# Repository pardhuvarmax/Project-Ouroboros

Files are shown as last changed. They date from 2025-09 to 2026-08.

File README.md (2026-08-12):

# Project Ouroboros – Unified Wireless Security Research
> ⚠️ **Disclaimer:** This project is for **educational, research, and ethical security purposes only**. Misuse of hardware or software is strictly the responsibility of the user.

---

## 🌐 Overview

**Project Ouroboros** is a **modular, dual-use cybersecurity platform** encompassing multiple ESP32-based hardware and firmware modules for **wireless defense, monitoring, and controlled research/offense experiments**.

It is structured as a parent ecosystem:

* **Blue Pill (Passive Development) :** Consumer-friendly, multi-layer defense shield (Wi-Fi, BLE, Sub-GHz) with anomaly detection and automated mitigation.
* **OuroMini:** Rapid-prototype dual-use demo board (15-day expo build) showcasing real-time wireless telemetry, visualization, and ghost traces.

The Ouroboros philosophy: **eternal cycle of attack & defense** — integrating visualization, telemetry, and interactive demos in a single hardware/firmware ecosystem.

---

## 🔹 Core Objectives

* **Defense:** Protect home, personal, and IoT networks from Wi-Fi, BLE, Sub-GHz attacks.
* **Research:** Safe experimentation of offensive tools for learning and controlled testing.
* **Visualization:** Real-time telemetry, ghost traces, waterfall spectrums, and dashboards for expos or lab demos.
* **Rapid Deployment:** Prebuilt `.bin` firmware, modular hardware, and standardized flashing for fast prototyping.
* **Extensibility:** Supports TinyML, AI-assisted anomaly detection, and additional RF front-ends.

---

## 🏗️ Sub-Projects & Modules

### Blue Pill – Defensive Shield

**Purpose:** Consumer-ready Wi-Fi/BLE/Sub-GHz network protection.

**Features:**

* Real-time intrusion detection (deauth, rogue AP, spoofing).
* TinyML anomaly detection for smarter threat recognition.
* Active countermeasures: automated mitigation, reconnection, and hardened configs.
* Spectrum visualization: waterfall graphs on OLED/TFT.
* Logging & optional dashboard telemetry.

**Hardware & Firmware:**

* ESP32-U/WROOM-32E, OLED/TFT, optional Sub-GHz & BLE modules.
* Firmware modularity allows independent updates for each protocol.

**Resources:**

* [Blue Pill Docs](./BluePill/Documentations)

---

### OuroMini – 15-Day Expo Prototype

**Purpose:** Rapid 15-day dual-use prototype for expos & demos.

**Highlights:**

* Real-time scanning: Wi-Fi, BLE, Sub-GHz.
* OLED visualization: RSSI bars, waterfall graphs, ghost-traces.
* Dual-mode toggle: Defensive vs. Research.
* SD card logging and optional dashboard telemetry.

**Hardware:** ESP32 MCU, OLED, minimal peripherals, external antennas.

**Firmware:** Modular scanning, menu-driven UI, safe demo constraints.

**Docs:** 
- [Ouromini Abstract](OuroMini/docs/ABSTRACT.md)
- [OuroMini Expo Documentation](./OuroMini/docs/EXPO.md)  
- [Architecture & Firmware Details](./OuroMini/docs/ARCHITECTURE.md)

---

### Modules

| Module | Purpose | Notes |
| --- | --- | --- |
| CC1101 / Sub-GHz | RF monitoring & replay | 315/433/868/915 MHz bands |
| NRF24L01 | Mesh/network testing | 2.4 GHz experimentation |
| PN532 / RFID-NFC | Tag scanning & emulation | Access control research |
| IR Transceiver | Consumer device capture/replay | NEC, RC5, Samsung, etc. |
| FM / Audio | Frequency scanning & demo | Visualization only |

---

## 🛠️ Hardware Requirements

**Core MCU:**

* ESP32-U / S3 for more RAM and peripherals.

**Optional:**

* OLED / TFT display (visualization & menus)
* External antennas for Wi-Fi/BLE/Sub-GHz
* Shields/modules for advanced research

---

## 💻 Software Stack

**Firmware Base:**

* [ESP-IDF](https://github.com/espressif/esp-idf)
* [Arduino-ESP32](https://github.com/espressif/arduino-esp32)

**Key Libraries:**

* WiFi, BLE, RadioLib (Sub-GHz)
* TensorFlow Lite Micro (TinyML)
* ArduinoJson, LittleFS, ESPAsyncWebServer
* U8g2, TFT_eSPI, LVGL for visualization

**Optional Tools:**

* HackRF / RTL-SDR for advanced RF
* Edge Impulse / TinyML SDKs

---

## 📂 Directory Structure

```
├───.github
├───BluePill
├───RedPill
├───OuroMini
│   ├───dashboard
│   ├───docs
│   ├───firmware
│   ├───graphics
│   ├───hardware
│   ├───media
│   └───tools
└───Docs
```

---

## 📚 Learning & Contribution Roadmap

1. Learn **ESP32 basics** → Wi-Fi, BLE, FreeRTOS.
2. Implement **Wi-Fi monitoring & defense** → deauth, rogue AP detection.
3. Explore **BLE & Sub-GHz experimentation** → spoofing, jamming, replay attacks.
4. Add **visualization & dashboards** → OLED/TFT/ESPAsyncWebServer.
5. Integrate **TinyML / AI models** → anomaly detection for defense.
6. Combine **offensive & defensive modules** → multitasking with FreeRTOS.
7. Extend **Shields & peripherals** → advanced RF and sensor experiments.

---

## 🔗 References

* [Espressif ESP32 Documentation](https://docs.espressif.com)
* [OWASP Wi-Fi Security Guide](https://owasp.org/www-project-wi-fi-security-testing-guide/)
* [NIST Wi-Fi Security Guidelines (SP 800-153)](https://csrc.nist.gov/publications/detail/sp/800-153/final)
* [HackRF Spectrum Analyzer](https://github.com/pavsa/hackrf-spectrum-analyzer)
* [TensorFlow Lite Micro](https://www.tensorflow.org/lite/microcontrollers)
* [Edge Impulse](https://edgeimpulse.com)

---

## 📜 License

**Project Ouroboros** © 2025 
Licensed under **GNU GPL-3.0** – use, modify, and redistribute under GPL terms. See [LICENSE](LICENSE).

## Credits & Attribution

- OuroMini's firmware is derived from ESP32 Marauder by Just Call Me Koko, originally released under the MIT License (Copyright © 2020 Just Call Me Koko). Marauder was itself inspired by Spacehuhn's esp8266_deauther.
What OuroMini changes: ported to ESP32-WROOM-32 as a headless target, removed the display, touch and on-device menu subsystems, and rebuilt the interaction layer around a web dashboard and serial/UART interface. See docs/ARCHITECTURE.md for the full breakdown.

- OuroMini as a whole is licensed under GNU GPL-3.0. The original MIT-licensed Marauder components remain under their original terms, and the upstream notice is retained in LICENSE-MIT.

---

✅ **This README serves as the central hub** for the entire Ouroboros ecosystem: **Blue Pill, Red Pill, OuroMini, Shields, and optional modules**, providing newcomers and contributors with the **complete project overview, architecture, and references**.

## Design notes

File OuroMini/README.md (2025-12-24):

# OuroMini Logo

**Ouroboros Mini (OuroMini)** — *ESP32-based experimental wireless monitoring & security testing platform (headless variant)*
Engineered as a **15-day rapid prototype**, OuroMini focuses on **dual-use** capabilities (defensive monitoring + controlled offensive research) for educational, research and expo demonstrations.
This document is the **headless / ESP32-WROOM-32 only** edition — all features and notes reflect that hardware constraint.

---

## 🔬 Project Objective

1. Deliver a **compact, cross-protocol wireless research platform** focused on capabilities realistically supported by the ESP32-WROOM32: **Wi-Fi (2.4 GHz)** and **Bluetooth Low Energy (BLE)**, plus IR and simple GPIO peripherals where hardware is present.
2. Provide **real-time telemetry & visualization** via a web dashboard and serial/UART (headless device → browser/dashboard on host).
3. Enable **signal capture and export** for offline analysis and demonstration (handshake export, packet logs).
4. Demonstrate **wireless anomaly detection, telemetry visualization, and repeatable expo demo sequences**.
5. Act as a **modular research artifact** (firmware + logging + demo scripts) for teaching and conferences.

---

## ⚠️ Dual-Use & Legal Considerations

Warning

> **Warning:** OuroMini is intended solely for ethical research, education and authorized security testing. Unauthorized use on networks/devices you do not own or have explicit permission to test is illegal. Comply with local wireless regulations (FCC/CE/others). Operators are responsible for lawful use. The project authors disclaim liability for misuse.

---

## ⚙️ Full Feature Set

| Protocol Layer | Features | Notes |
| --- | --- | --- |
| **Wi-Fi (2.4 GHz)** | - Network scanning (active + passive), AP/client enumeration, RSSI mapping<br>- Promiscuous-mode packet capture (2.4 GHz frames) & basic frame logging<br>- WPA handshake capture (exportable for offline cracking workflows)<br>- Targeted 2.4 GHz deauthentication (single & multi-target)<br>- Beacon creation / fake AP (SSID advertise / SSID flood)<br>- Evil Portal (captive-AP + hosted captive web page for demo/credential capture)<br>- Wardriving (scan + time-stamped LittleFS/SD logging) | **Headless ESP32-WROOM32 only — NO 5 GHz.** DPI beyond basic frame capture is limited by MCU resources. Use offensive actions only in authorized demos. |
| **Bluetooth (BLE)** | - BLE scanning (advertisements, RSSI logging) and presence tracking<br>- BLE advertising (beacon / peripheral emulation)<br>- Basic GATT server (simple characteristic read/write demos) | BLE features use the ESP32 BLE stack. Complex OS-level HID injection or advanced MITM is unreliable and platform-dependent. |
| **IR / GPIO (optional)** | - IR capture & replay sequences (if IR TX/RX hardware present)<br>- GPIO inputs (kill-switch) and outputs for LED indicators / external triggers | Optional per-device hardware. IR active features require an IR transmitter module fitted to the board. |
| **System / UX / Ops** | - LittleFS / SD capture logging (timestamped files)<br>- Web dashboard & WebSocket telemetry (hosted on AP/STA by the ESP)<br>- HTTP API / Web CLI endpoints for remote control (headless UI)<br>- OTA firmware update support (HTTP / PlatformIO compatible)<br>- UART / Serial CLI (local console) for interactive use<br>- Thermal sensor readout (internal temp) & runtime reporting<br>- Kill-switch GPIO input (hardware emergency disable handler)<br>- Rate-limiting controls for floods (configurable values)<br>- Timestamped operator/action logging to LittleFS | Headless operation — UI exposed via web dashboard or serial. All features above are implementable on stock WROOM32. |

---

## OuroMini Feature Classification: Defensive, Dual-Use, and Offensive Capabilities

| Category | Count | Example Features / Notes |
| ---: | ----: | --- |
| **Defensive** | 12 | Passive monitoring and analysis: <br>- Wi-Fi scanning (passive/active), AP/client enumeration, RSSI mapping<br>- BLE scanning & beacon tracking<br>- Promiscuous frame capture (2.4 GHz) & WPA handshake capture (for offline analysis)<br>- Wardriving + timestamped LittleFS/SD logging<br>- LittleFS/SD logging & operator/action audit trail<br>- Web dashboard & WebSocket telemetry (read/visualize)<br>- Thermal sensor reporting & UART CLI. |
| **Neutral / Dual-Use** | 7 | Passive or active depending on operator intent: <br>- BLE advertising / peripheral emulation (demo uses)<br>- Basic GATT server (demo/control)<br>- Beacon creation / fake AP advertising (gentle demo → aggressive flood)<br>- ESP-NOW send/receive (monitoring vs transmit)<br>- HTTP API / Web CLI control (read vs trigger active modules)<br>- Rate-limiting controls (demo intensity tuning)<br>- OTA / firmware update (maintenance or remote update). |
| **Offensive** | 6 | Active disruption (expo/lab/demo usage only): <br>- Targeted 2.4 GHz deauthentication (single/multi target)<br>- Deauth flood (rate-limited by config)<br>- Beacon spam / fake AP floods (SSID flood)<br>- Evil Portal (captive page for credential capture — demo only)<br>- Active handshake capture (for export and offline cracking workflows)<br>- ESP-initiated ESP-NOW transmissions (control frames) <br>**Note:** These features exist on the WROOM32 and are available for authorized demos. Know local law and expo rules. |

---

## 🛠️ Hardware Architecture

* **MCU:** ESP32-WROOM-32 (single module headless board)
* **Storage:** LittleFS on internal flash; optional microSD for large capture volumes (if socket fitted)
* **I/O (common builds):** UART, SPI, I²C, ADC, GPIOs, optional IR TX/RX pins, kill-switch GPIO header
* **Power:** USB-C / 5V input (depending on carrier board) with basic power regulation and thermal monitoring

> Note: This README targets the *mainboard-only* headless variant. External radios (Sub-GHz, NFC, NRF24) and native USB HID (S2/S3) are **not present** on this variant.

---

## 💻 Firmware Overview

* **Framework:** Arduino-ESP32 (primary) — fast deploy + familiar toolchain. ESP-IDF variants possible for advanced builds.
* **Repository layout (recommended):**

```
firmware/
├── src/         # main.ino, config.h, core modules
├── libs/        # drivers: wifi-utils, ble-utils, ir (if present)
├── modules/     # scanning, capture, evil-portal, deauth, espnow
├── tools/       # export scripts (handshake, logs)
└── binaries/    # precompiled .bin for rapid flashing
```

* **Core functionality:** Wi-Fi/BLE scanning, handshake capture & export, packet logging, LittleFS logging, web dashboard endpoint, thermal reporting.
* **Build / Flash:** PlatformIO / Arduino CLI / Espressif Flash Tool. Provide `ouromini-expo.bin` prebuilt for the expo.

---

## 🌐 Web Dashboard (Headless → Host UI)

Minimal, high-visibility dashboard optimized for expo demos and headless operation:

* Device presence (Wi-Fi / BLE) table
* RSSI graphs (short history)
* Live detection flags & alert log (timestamped)
* Device health (temp, uptime, memory)
* Control endpoints: start/stop scan, trigger demo sequence, fetch logs

```
dashboard/
└── design/    # Figma / static prototypes
```

> The ESP hosts a tiny webapp on captive AP or on STA (if connected).

---

## 📄 Documentation (repo)

* `docs/Abstract.md` — Overview & research rationale
* `docs/Architecture.md` — Hardware & firmware mapping (headless board)
* `docs/Firmware_Flow.md` — Module descriptions & compile flags (expo build notes)
* `docs/Expo_Presentation.md` — Demo scripts, safety scripts, and operator checklist
* `docs/Dashboard_Design.md` — UI flows & API endpoints

---

## 🔧 Safety & Operational Guidelines

* **Operator responsibility:** Only run offensive features in authorized controlled demos. Document consent and locale rules.
* **Expo setup:** Prefer a controlled demo area; inform venue and nearby exhibitors if performing disruptive demos.
* **Kill switch:** Hardware kill switch connected to GPIO should immediately disable radio TX when asserted.
* **Rate limits:** Configure conservative defaults for floods during demos; set operator-controlled intensity.
* **Audit:** All active actions MUST be logged (timestamp + operator ID) to LittleFS for post-demo audit.

---

## 📜 License

**Project Ouroboros** © 2025 **REVA4 Research Initiative**
Licensed under **GNU AGPL-3.0** — use and redistribution under AGPL terms. See `LICENSE` for details.

---

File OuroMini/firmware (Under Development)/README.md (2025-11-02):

# Ouroboros Mini – Firmware Overview & Flow (Headless ESP32-WROOM32)

## Overview

The **Ouroboros Mini (OuroMini)** firmware is a **15-day rapid prototype** firmware optimized for **dual-use wireless security research** on a headless **ESP32-WROOM-32** board.
Focus areas: **Wi-Fi (2.4 GHz)** and **Bluetooth Low Energy (BLE)** scanning/telemetry, on-device capture/export, web-hosted dashboards, and modular demo sequences. Optional carrier-board peripherals (IR TX/RX, microSD, LEDs, kill switch) are supported if present.

**Scope**

* On-device scanning and capture for Wi-Fi (2.4 GHz) and BLE.
* Real-time telemetry for expo demos via a small web dashboard hosted by the ESP.
* Local logging to LittleFS (internal flash) and optional microSD.
* Modular architecture for rapid feature integration and iteration.
* High-visibility demo sequences for authorized expo/lab environments.

> ⚠️ **Legal/Operational Warning:** Any high-impact offensive features (deauth, Evil Portal, packet injection, active transmissions) must only be used in authorized, controlled environments. Follow local wireless regulations and venue rules.

---

## Repo Layout

```
firmware/
│
├── source/
│   ├── main.ino            # Core loop, setup, lightweight scheduler
│   ├── modules/            # wifi/, ble/, ir/ (if present), utils/
│   ├── libs/               # drivers: oled, websocket, logging utilities
│   └── config.h            # feature toggles & constants (expo_config.h variant)
│
├── binaries/               # prebuilt .bin (ouromini-expo.bin, ouromini-safe.bin)
├── docs/                   # docs/Expo_Presentation.md, Architecture.md, etc.
└── flashing.md             # flashing & quick start instructions
```

---

## Key Modules & Feature Matrix

> **Hardware baseline:** ESP32-WROOM-32 only (headless). Features marked *Optional HW* require extra components on the carrier board (microSD, IR LED/receiver, external sensors).

| Feature / Module | Type | Status | Notes |
| --- | --- | --- | --- |
| Wi-Fi Scanner | Defensive | Stable | Passive & active scan, AP/client enumeration, RSSI mapping. |
| Wi-Fi Packet Capture | Defensive | Stable | Promiscuous 2.4 GHz frame capture & basic logging (limited DPI). |
| WPA Handshake Capture  | Defensive | Stable | Capture for export (offline cracking off-device). |
| Deauth / Flood | Offensive | Experimental | 2.4 GHz targeted deauth and rate-limited floods; expo/lab use only. |
| Beacon / Fake AP | Neutral | Stable | Create SSIDs / fake APs; flood intensity configurable. |
| Evil Portal | Offensive | Experimental | Captive portal hosting on AP — demo credential capture only. |
| BLE Scanner | Defensive | Stable | Advertisement scanning, RSSI logging, presence tracking. |
| BLE Advertiser / GATT  | Neutral | Stable | Beacon/peripheral emulation, basic GATT server (demo control). |
| IR Capture / Replay *  | Neutral | Optional | Requires IR TX/RX hardware on carrier board. |
| LittleFS / microSD Log | Defensive | Stable | Timestamped CSV/PCAP-lite logs; microSD optional for large captures. |
| Web Dashboard / API | Neutral | Stable | WebSocket telemetry, HTTP API endpoints (hosted by ESP). |
| UART / Serial CLI | Ops | Stable | Local serial CLI for interactive debugging. |
| Thermal Sensor Readout | Ops | Stable | Internal temperature sensor reporting. |
| Kill-Switch GPIO | Safety | Stable | Hardware input to immediately disable TX features when asserted. |
| OTA Update (HTTP) | Ops | Stable | Simple HTTP OTA for controlled environments. |
| BADUSB / Native USB* | Offensive | UNAVAILABLE  | **Not supported on WROOM32 (ESP32-S2/S3 required).** |
| Sub-GHz / NRF24 / NFC* | Neutral/Offensive | UNAVAILABLE  | Require external radio modules/shields; not part of headless baseline. |

* Optional or unavailable items are supported only if the carrier board includes the required hardware (marked clearly).

---

## Firmware Flow (High Level)

1. **Boot & Init**

   * Boot ROM → app starts.
   * Initialize logging (LittleFS), serial console, thermal sensor.
   * Probe for optional hardware (microSD, IR, LEDs); mount if present.
   * Load `config.h` / runtime config (expo vs safe build).

2. **Network & Radio Setup**

   * Wi-Fi driver: configure station/AP modes as requested; enable promiscuous if capture enabled.
   * BLE stack: start advertisement scanning and optional peripheral services.
   * IR module (if present): initialize capture hardware.
   * Configure web server & WebSocket endpoints.

3. **Main Loop — Scanning & Buffering**

   * Run periodic scan tasks (Wi-Fi, BLE) on configurable intervals.
   * Buffer captured frames/adv packets in RAM (ring buffer) for short-term visualization.
   * Flush logs to LittleFS or microSD every N seconds or when buffer full.

4. **Demo / Active Modules**

   * Operator triggers demo sequence via Web CLI or scheduled script.
   * Offensive modules (deauth, fake AP, Evil Portal) start only when explicitly commanded.
   * Respect configured rate-limits and enforce temporary TX backoff on errors.

5. **Visualization & Telemetry**

   * WebSocket pushes short history: device lists, RSSI timeseries, alerts.
   * Serial CLI available for live control and debug.
   * Optional minimal OLED or LED feedback if carrier board has them.

6. **Error Handling & Recovery**

   * File IO: retry writes; rotate logs on SD errors.
   * Watchdog timer resets on fatal deadlocks after graceful shutdown attempt.
   * Module restart on non-fatal driver failures (e.g., BLE stack hiccups).

---

## Development Notes & Tooling

* **Primary Framework:** Arduino-ESP32 (fast iteration). ESP-IDF port recommended for advanced/performance builds.
* **Toolchain:** PlatformIO (recommended) or Arduino CLI + esp32 core. Use `esp32dev` board profile for WROOM32 carriers.
* **Key libs:** `WiFi.h`, `esp_wifi_promiscuous.h` utilities, `NimBLE-Arduino` / `ESP32 BLE Arduino` stack, `AsyncWebServer` / `WebSockets`.
* **Structure tips:** Keep offensive TX code in isolated modules/files and call through guarded APIs to make auditing easier.
* **Prebuilt binaries:** Provide `ouromini-expo.bin` (full demo) and `ouromini-safe.bin` (observability only) if you want two release options — though the headless expo build can include all feasible features by default per your expo needs.

---

## Flashing Procedure (ESP32-WROOM-32 headless)

1. Connect via USB-to-serial (FTDI/CP210x/CH340) to your carrier board.
2. Use PlatformIO `pio run -t upload` or `esptool.py` / Espressif Flash Tool. Example `esptool.py` command:

```bash
esptool.py --chip esp32 --port /dev/ttyUSB0 write_flash -z \
  0x1000 bootloader.bin 0x8000 partitions.bin 0x10000 ouromini-expo.bin
```

3. If using Arduino IDE, select `ESP32 Dev Module` / appropriate flash size & flash the `.bin`.
4. Verify: serial output should show boot banner, config, mounted LittleFS (or SD) and IP for captive AP (if started).

> Note: WROOM32 does not support native USB device HID (BADUSB). Do not attempt S2/S3 toolchain instructions on WROOM32 builds.

---

## Limitations & Notes (Headless Expo Build)

* **No native USB HID (BADUSB)** on WROOM32 — remove USB HID workflows or require S2/S3 hardware.
* **No built-in Sub-GHz / NRF24 / NFC / FM** — these need shields or external radios; the firmware contains hooks but will hide unavailable menus if hardware not present.
* **DPI is limited** — the MCU cannot perform full DPI; store captures for offline analysis on a PC.
* **Thermal & power:** Continuous TX + heavy logging increases device temp and power draw — monitor thermal values in the Web UI.
* **Regulatory:** Be sure to obtain permission for any active transmissions or disruptive demos.

---

## Recommended Expo Checklist (headless)

* Verify carrier board has microSD (if large logs), IR (if demo needs IR), and kill-switch wired.
* Preload `ouromini-expo.bin` and test offline handshake capture → export.
* Prepare one scripted demo sequence (scan → fake AP → evil portal → deauth burst) and rehearse in RF-safe area.
* Ensure venue permissions; inform neighboring booths if demo includes active TX.
* Keep physical kill-switch accessible and tested.

---

## Summary

This headless-focused firmware targets robust **Wi-Fi (2.4 GHz)** and **BLE** research & demo workflows on an **ESP32-WROOM-32** platform with optional carrier-board peripherals. The firmware is modular and optimized for quick expo demonstration while keeping a clear separation between passive monitoring and explicit active demo modules.

---



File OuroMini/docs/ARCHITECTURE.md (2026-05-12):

# Ouroboros Mini – System Architecture (Updated)

## Overview
Ouroboros Mini (OuroMini) represents a compact, dual-use embedded system designed for real-time wireless analysis, visualization, and interactive cybersecurity demonstrations. Built under an accelerated 15-day development cycle, the architecture balances modular expandability with hardware efficiency — optimized for research expos, educational demos, and controlled security environments.

Its structure mirrors the core Ouroboros philosophy: the eternal cycle of defense and offense, unified under a single hardware and firmware ecosystem.

## Hardware Architecture

### Mainboard Core
- **ESP32-WROOM-32U (or 32E)** – Central MCU providing Wi-Fi (2.4GHz) and BLE capabilities with U.FL antenna connector for extended range.
- **TP4056** – Li-Ion charge controller with integrated protection (overcharge/overcurrent).
- **LF33 Regulator** – Stable 3.3V LDO powering MCU and modules.
- **CP2102 Interface** – USB-to-UART bridge for debugging, flashing, and USB power input.
- **OLED Display (SSD1306 / SH1106)** – Low-power visualization unit for live telemetry, menus, and signal waterfalls.
- **SD Card Slot (SPI)** – On-device logging of telemetry, configs, signal captures, and replay files.
- **Antenna Connectors (SMA/U.FL)** – External antennas for Wi-Fi, BLE, and Sub-GHz signal optimization.
- **Battery & Power System** – 3.7V Li-Ion cell with on-board charge and protection circuitry.

### Peripheral Expansion
- **CC1101 (Sub-GHz)** – Signal read/replay, spectrum visualization, replay profiles (315/433/868/915 MHz).
- **NRF24L01+** – Mesh/network testing, packet sniffing, and signal interference demos.
- **PN532 / RFID-NFC** – Tag scanning, cloning, and emulation for access system research.
- **IR Transceiver** – Capture/replay for consumer IR devices (NEC, RC5, Samsung, etc.).
- **FM & Audio (Optional)** – Basic frequency scanning and broadcast control for demo visualization.

### Signal Flow
1. **Acquisition:** Radios (Wi-Fi/BLE/Sub-GHz) capture and timestamp raw signal data.
2. **Processing:** MCU filters, classifies, and structures packets for visualization/logging.
3. **Visualization:** OLED renders RSSI bars, live waterfall spectrums, ghost traces, and packet activity.
4. **Storage:** Data logged to SD/LittleFS in structured folders (WiFi, BLE, SubGHz, Logs).
5. **Communication (optional):** Telemetry exported to web dashboard or WireGuard-tunneled relay.

## Firmware Architecture

### Modular Design
| Module | Function | Description |
|---|---|---|
| Scanner Core | Acquisition | Cyclic Wi-Fi/BLE/Sub-GHz scanning with adaptive interval control. |
| Analyzer | Processing | Converts raw RSSI data into heatmaps, histograms, and trend buffers. |
| Logger | Storage | Writes logs to SD, timestamps events, and rotates files by protocol type. |
| Display/UI | Visualization | Handles OLED rendering, ghost-trace overlays, orientation, and dim control. |
| Configuration | Management | Centralized in `config.h` or `/config.json` on SD for runtime overrides. |
| Communication | Networking | Web server, WireGuard, Telnet/SSH, ESP-NOW exchange. |
| Defensive Suite | Protection | Passive intrusion detection, beacon pattern deviation alerts, wardriving telemetry. |
| Offensive Suite | Research | Beacon spam, deauth, Evil Portal, BLE spoof, RF replay (disabled by default). |
| Safety Core | Compliance | Watchdog, rate-limiter, and failsafe mode toggles for safe demo use. |

### Execution Flow
```
Boot → Init Hardware → Config Load 
    ↓
Scan Cycle: Wi-Fi / BLE / Sub-GHz
    ↓
Analyze + Log → OLED Render + Ghost Overlay
    ↓
Optional: Send JSON Telemetry → Dashboard
    ↓
Repeat (Adaptive Loop)
```

**Failsafe Layers:**
- Watchdog resets on scan or display timeout.
- SD card I/O errors trigger fallback to serial-only mode.
- Dual-mode toggle (Defensive / Research) enforces demo safety boundary.

## Dashboard & Telemetry Architecture (Optional)
- **Front-End:** HTML/JS-based dashboard visualizes device count, RSSI charts, and frequency heatmaps in real time.
- **Back-End:** Lightweight Python Flask API for receiving telemetry and broadcasting via WebSocket.
- **Transport:** ESP32 sends JSON payloads (Wi-Fi scan, BLE metrics, alerts) over HTTP or WireGuard-secured channel.
- **Integration:** Compatible with Grafana/InfluxDB backends for extended analysis or data archiving.

## Design Considerations
| Aspect | Description |
|---|---|
| Dual-Nature Design | Hardware and firmware inherently support both passive defense and active testing modes, switchable via compile-time or menu configuration. |
| Modularity | Each subsystem (Wi-Fi, BLE, Sub-GHz, UI, Dashboard) is isolated for independent debugging and expansion. |
| Safety by Design | Built-in restrictions and toggles ensure demonstrations stay compliant. |
| Extensibility | Framework supports integration of TinyML models, new RF front-ends, and adaptive learning modules in later versions. |
| Reproducibility | Consistent hardware references, prebuilt `.bin` files, and modular code ensure identical deployment results. |

## Summary
Ouroboros Mini exemplifies a miniaturized yet scalable system architecture capable of demonstrating multi-protocol wireless introspection, on-device telemetry visualization, and ethical attack-defense research.

The design emphasizes:
- **Modularity** – Seamless swapping of radio modules.
- **Transparency** – Clear visual representation of wireless activity.
- **Safety** – Dual-mode architecture preventing misuse.
- **Reproducibility** – Ready-to-flash firmware for rapid expo deployment.

It stands as a proof-of-concept platform showcasing the balance between creation and destruction, defense and offense, and hardware and intelligence — true to the Ouroboros spirit.

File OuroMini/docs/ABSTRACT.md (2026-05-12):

# Ouroboros Mini – Abstract

## Project Overview

**Ouroboros Mini** is a compact, dual-nature wireless cybersecurity prototype engineered for high-impact demonstration within a constrained 15-day development cycle. It merges embedded telemetry, spectrum visualization, and local data intelligence into a single, handheld form factor. Designed for expos, research showcases, and educational demonstrations, OuroMini emphasizes visual clarity, modular firmware, and low-cost scalability over commercial complexity.

---

## Objective

The core goal of Ouroboros Mini is to **illustrate the balance between wireless monitoring, analysis, and control** through a single, self-contained microcontroller platform. It acts as both a **defensive diagnostic tool** and a **research-grade testbed** for wireless security exploration, highlighting real-time signal behavior across Wi-Fi, BLE, and optional Sub-GHz bands.

---

## Scope & Limitations

* **Scope:** Demonstrates Wi-Fi and BLE scanning, live spectrum rendering, telemetry logging, and optional dashboard-based data visualization.
* **Limitations:**

  * No TinyML/AI-based anomaly detection (reserved for full Ouroboros build).
  * Sub-GHz, NFC, and RF replay features partially stubbed or deactivated.
  * Certain offensive capabilities are research-locked and not deployed in demo mode.
* **Usage Note:** Strictly experimental — for controlled, lawful environments only.

---

## Technical Highlights

* **MCU Platform:** ESP32-WROOM-32U (16 MB) with integrated Wi-Fi + BLE, SPI, UART, and GPIO expandability.
* **Visualization Layer:** 0.96" OLED or 2.8" TFT (ILI9341) for on-device telemetry and spectrum graphing.
* **Logging & Storage:** MicroSD SPI slot for local data capture, session replay, and forensic export.
* **Connectivity Modules:** NRF24L01 transceivers, BLE scanner, optional Sub-GHz stub for RF spectrum sampling.
* **Firmware Architecture:** Modular C++/Arduino framework supporting detachable offensive/defensive subsystems.
* **Deployment:** Ready-to-flash precompiled `.bin` images; supports UART, SD, or OTA flashing for rapid demo setup.

---

## Impact

Ouroboros Mini stands as a **symbol of accelerated engineering discipline**, compressing hardware design, firmware integration, and UI logic into a functioning, exposable prototype. It enables cybersecurity educators, researchers, and enthusiasts to observe real-time wireless phenomena in a tangible, interpretable form.

By merging hardware telemetry with human-readable visualization, OuroMini embodies the philosophy of **Project Ouroboros** — the eternal cycle of attack and defense — rendered through practical, educational hardware experimentation.

---

**Disclaimer:**
This firmware and hardware are strictly for **educational and authorized research purposes**.
Unauthorized or unlawful usage of wireless interference features may violate regional regulations.

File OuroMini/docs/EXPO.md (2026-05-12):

# Ouroboros Mini 15-Day Expo Presentation

## Overview
Ouroboros Mini (OuroMini) is a compact, dual-use experimental wireless monitoring and defense platform, built under an accelerated 15-day development cycle. Designed for research expos, educational demos, and controlled cybersecurity demonstrations, the prototype emphasizes modular expandability, real-time visualization, and interactive engagement over full-scale production features.

It embodies the Ouroboros philosophy: the eternal cycle of defense and offense, unified in a single hardware and firmware ecosystem.

## Project Objective
The primary objective of the Ouroboros Mini is to provide a tangible demonstration of multi-protocol wireless security and telemetry in a highly compressed development timeframe. It highlights:

- Real-time scanning and visualization for Wi-Fi, BLE, and Sub-GHz signals.
- Basic defensive analytics and simple offensive research demonstrations in a safe, expo-ready format.
- Interactive OLED visualization, including RSSI bars, waterfall spectrums, and ghost-trace overlays for audience comprehension.

## Key Highlights
- **Rapid Prototyping:** Complete functional prototype from PCB baseline to operational demo in 15 days.
- **Expo-Ready Visualization:** Interactive OLED display and optional web dashboard for clear audience engagement.
- **Dual-Use Demonstration:** Supports passive defense and controlled research operations, switchable for safety.
- **Simplified Engineering:** Focused on firmware modularity and visualization rather than complex AI/TinyML integration.

## Architecture & Integration
Ouroboros Mini merges hardware, firmware, and visualization into a single cohesive demonstration unit, emphasizing modularity, clarity, and rapid development.

### Main Components
- **ESP32-WROOM-32U/E (16MB):** MCU for wireless scanning, processing, and UI rendering.
- **OLED Display (SSD1306 / SH1106):** Low-power display for real-time telemetry, ghost traces, and menu navigation.
- **SD Card Slot (SPI):** Logging of Wi-Fi, BLE, Sub-GHz data, configuration, and replay files.
- **External Antennas (U.FL/SMA):** Optimized reception for Wi-Fi, BLE, and Sub-GHz.

**Peripheral Modules (Optional):**
- CC1101 (Sub-GHz)
- NRF24L01+ (mesh/network testing)
- PN532 / RFID-NFC (tag scanning & emulation)
- IR transceiver (capture/replay)
- FM/audio visualization

### Firmware Flow
- **Initialization:** Boot, hardware detection, configuration load.
- **Scan Cycle:** Wi-Fi, BLE, and Sub-GHz signal acquisition.
- **Analysis & Logging:** RSSI measurement, basic anomaly detection, and structured logging to SD.
- **Visualization:** OLED renders live bars, waterfall spectrums, and ghost traces.
- **Optional Telemetry:** JSON-formatted data sent to dashboard via HTTP or WireGuard tunnel.
- **Loop:** Adaptive scan → analysis → render → optional telemetry → repeat.

### Safety & Demo Constraints
- Watchdog timers reset on scan/display failures.
- SD card I/O errors fallback to serial-only logging.
- Dual-mode toggle (Defensive / Research) enforces safe demonstration limits.

## Hardware Setup for Expo
The 15-day build focused on **core demonstration hardware** for rapid deployment:
- Fully assembled mainboard with ESP32, OLED, and minimal peripherals.
- Battery connected via TP4056 module.
- External antennas attached for Wi-Fi/BLE demonstration.
- No additional Shield modules integrated to maintain assembly simplicity.

## Firmware & Flashing
- Firmware adapted from a pre-existing prototype `.bin` for fast deployment.
- Modular scanning routines and menu-driven OLED UI for live interaction.
- SD card logging and optional JSON telemetry for visual evidence.
- Flashing performed using **esptool or Arduino IDE**, supporting OTA updates and runtime adjustments.

## Demo Scenario
Audience demonstration workflow:
1. **Power-On:** Device boot sequence on OLED display.
2. **Signal Scan:** Real-time visualization of Wi-Fi, BLE, and Sub-GHz signals.
3. **Interaction:** Buttons or menu navigation to inspect specific channels/protocols.
4. **Event Indication:** Simple visual alerts for rogue APs, interference, or beacon deviations.

This scenario allows audiences to quickly grasp core wireless security principles through tangible, real-time feedback.

## Key Takeaways from 15-Day Build
- **Feasibility:** Rapid condensed development can produce a functional dual-use wireless defense prototype.
- **Team Coordination:** Effective delegation of firmware, PCB assembly, and UI visualization was critical.
- **Rapid Iteration:** Leveraging pre-existing firmware accelerated UI and scan visualization enhancements.
- **Demo Focus:** Audience comprehension prioritized over full technical depth ensured successful exposition.

## Future Directions
Post-expo, Ouroboros Mini can be enhanced by:
- Integrating Shield modules for BLE/Sub-GHz countermeasures.
- Adding TinyML/AI modules for anomaly detection and adaptive scanning.
- Expanding web dashboard for remote monitoring, historical logs, and analytics.
- Supporting additional RF modules and advanced offensive/defensive research tools.

## Conclusion
The Ouroboros Mini 15-Day Expo Build is a **proof-of-concept dual-use wireless security platform**, emphasizing interactive visualization, modular design, and rapid engineering feasibility. It demonstrates how condensed development can effectively showcase multi-protocol monitoring, ethical attack-defense research, and real-time telemetry to audiences in an expo-ready, visually engaging format.

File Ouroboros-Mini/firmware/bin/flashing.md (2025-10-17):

# Firmware Upload Guide for OuroMini (Ouroboros Mini)

The OuroMini (Ouroboros Mini) requires firmware or code to unlock its wireless capabilities. This guide covers three methods to upload firmware: OTA/SD Card, Flash Download Tool, and Arduino IDE. These methods suit both beginners and advanced users working with the mini prototype.

⚠️ **Note:** Always download firmware and sketches from the OuroMini repository.

---

## Method 1: Update Firmware via OTA or SD Card

If your OuroMini is running its main firmware, use the built-in update feature via Over-The-Air (OTA) or SD card. This method is ideal for quick, computer-free updates using the TFT display.

### What You’ll Need
- Working OuroMini with main firmware and functional TFT display.  
- MicroSD card (FAT32 formatted) for SD card updates.  
- `.bin` firmware file from the repository.  
- Wi-Fi credentials for OTA updates.  
- Computer or phone to host the firmware file for OTA.

### Steps for OTA Update

**Get the Firmware File:**
- Download the latest `.bin` file from the OuroMini GitHub repository.  
- Host it on a server or computer and note the URL (e.g., `http://192.168.1.100/firmware.bin`).  

**Connect to Wi-Fi:**
- Power on the OuroMini. Go to Wi-Fi Settings on the TFT display.  
- Select your network, enter the password using the on-screen keyboard, and connect.

**Run the OTA Update:**
- Navigate to Firmware Update menu, select OTA Update, and enter the firmware URL.  
- Press Update to download and flash. The device reboots when done.

**Check the Update:**
- Verify the new firmware version on the TFT display or Serial Monitor (115200 baud).  
- If it fails, check the URL and Wi-Fi stability, then retry.

### Steps for SD Card Update

**Prepare the SD Card:**
- Format a microSD card to FAT32.  
- Download the latest `.bin` file from the repository and rename it to `firmware.bin`.  
- Place `firmware.bin` in the SD card’s root directory and eject safely.

**Insert the SD Card:**
- Power off the OuroMini and insert the SD card.

**Run the SD Card Update:**
- Power on, go to Firmware Update, and select SD Card Update.  
- Select `firmware.bin` and press Update. The device reboots after flashing.

**Check the Update:**
- Confirm the firmware version on the TFT display or Serial Monitor.  
- The file may be renamed (e.g., `firmware.bak`). Remove or reformat the SD card for future use.

**Tips:**
- OTA: Ensure a strong Wi-Fi signal and keep the host online.  
- SD Card: Use a reliable microSD card. Power off before inserting/removing.  
- Troubleshooting: Verify the `.bin` file, ensure FAT32 format, or check Serial Monitor for errors.

---

## Method 2: Flash a `.bin` File with Flash Download Tool

Use the Espressif Flash Download Tool to upload firmware via USB. This is suitable for initial setups or restoring a non-working OuroMini.

### What You’ll Need
- OuroMini with USB-C/micro-USB port.  
- Computer (Windows, macOS, Linux).  
- USB cable.  
- `.bin` firmware file from the OuroMini repository.  
- `.partitions` firmware file from the repository.  
- Espressif Flash Download Tool.

### Steps

**Prepare the Firmware File:**
- Download the `.bin` and `.partitions` files from the repository.

**Install the Flash Download Tool:**  
- Download and install the tool. Run as administrator on Windows.

**Connect the OuroMini:**
- Connect via USB and enter Download Mode:  
  Hold **BOOT** button, press **RESET** briefly, release both.  
- Select the correct COM port in the tool.

**Configure Flash Settings:**
- Select ESP32 chip type and Developer Mode or Download Mode.  
- Load the `.bin` file, set flash offset to `0x10000`.  
- Load the `.partitions` file, set flash offset to `0x8000`.  
- Set SPI Speed to 40 MHz, SPI Mode to DIO.  
- Check the `.bin` and `.partitions` file boxes.

**Flash the Firmware:**
- Click **START**. Wait for “FINISH” or “Download Complete” (1–2 minutes).

**Reset and Verify:**
- Power cycle the OuroMini. Check the TFT display or Serial Monitor for the new firmware version.  
- If it fails, verify COM port, offset, or Download Mode.

**Tips:**
- Install USB-to-serial drivers (e.g., CP2102, CH340) if needed.  
- Verify the `.bin` file matches your hardware.  
- Try a different USB cable/port or lower SPI Speed (20 MHz) if flashing fails.

---

## Method 3: Upload Sketch via Arduino IDE

Compile and upload the OuroMini sketch for customization. This method requires specific setup for the 4MB or 16MB ESP32 versions used in the mini.

### What You’ll Need
- OuroMini with USB-C/micro-USB port.  
- Computer with Arduino IDE (2.x or 1.8.x).  
- USB cable.  
- OuroMini sketch, library ZIP, and `platform.txt` from the repository.

### Steps

**Install Arduino IDE and ESP32 Board Package:**
- Install Arduino IDE.  
- Go to **Tools > Board > Boards Manager**, search “esp32,” and install **esp32 by Espressif Systems** (version 2.0.10).

**Replace platform.txt:**
- Download `platform.txt` from the repository.  
- Replace the file in:  
  - Windows: `C:\Users\<YOUR_USERNAME>\AppData\Local\Arduino15\packages\esp32\hardware\esp32\2.0.10`  
  - macOS: `~/Library/Arduino15/packages/esp32/hardware/esp32\2.0.10`  
  - Linux: `~/.arduino15/packages/esp32/hardware/esp32\2.0.10`  
- Back up the original.

**Replace Library Files:**
- Download the library ZIP from the repository and unzip it.  
- Replace existing library folders in:  
  - Windows: `C:\Users\<YOUR_USERNAME>\Documents\Arduino\libraries`  
  - macOS: `~/Documents/Arduino/libraries`  
  - Linux: `~/Arduino/libraries`  
- Restart the Arduino IDE.

**Download and Open Sketch:**
- Download the `.ino` sketch from the repository and open it in the IDE.

**Configure Arduino IDE Settings:**
- Connect the OuroMini via USB.  
- Select **Tools > Board > ESP32 Dev Module** and the correct Port.  
- Configure based on flash size:  
  - **4MB ESP32:** Partition Scheme: Rainmaker, Huge APP, or Minimal SPIFFS. Flash Size: 4MB.  
  - **16MB ESP32:** Partition Scheme: 16MB Flash (3MB APP/9.9MB FATFS). Flash Size: 16MB.  
- Optional: Set Upload Speed to 921600, CPU Frequency to 240 MHz.

**Compile and Upload:**
- Click **Verify** to compile. Fix any errors.  
- Click **Upload**. Enter Download Mode if prompted (hold **BOOT**, press **RESET**, release both).  
- Wait for “Done uploading.”

**Verify Upload:**
- Check the TFT display or Serial Monitor (115200 baud).  
- If it fails, verify settings, port, or Download Mode.

**Tips:**
- Ensure libraries match the ZIP file to avoid conflicts.  
- Install USB-to-serial drivers if the port isn’t detected.  
- Lower upload speed to 115200 or try another cable/port if needed.

> refer this, or alternatively [ESP32-DIV](https://github.com/cifertech/ESP32-DIV/tree/main) Wiki of **Cifertech**

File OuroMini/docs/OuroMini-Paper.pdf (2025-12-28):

## OuroMini: A Modular ESP32-Based Platform for Dual-Use Wireless Monitoring and Security Research

Pardhu Varma Konduru1,[1], Rupa Yeshvitha Karedla¹
, Venkata Hanu Sathya Sai Karthik Kanne¹

, Tejaswini Kandukoori1, Harshitha Belaganti¹ , Vamshi Kandunoori1, Jeswanth Kamutam1, Venkata Sathya Sai Kolusu

Malla Reddy University Hyderabad, Computer Science and Engineering (Cybersecurity), 500100, Hyderabad Telangana, India

{2311CS040089, 2311CS040082, 2311CS040080, 2311CS040077,

2311CS040022, 2311CS040078, 2311CS040072, 2311CS040088}@mallareddyuniversity.ac.in

Abstract. The modern digital ecosystem is increasingly dependent on wireless communication technologies, which form the backbone of contemporary networking infrastructures. As connectivity grows ubiquitous through Wi-Fi, Bluetooth, and emerging IoT protocols, so too do the associated cybersecurity risks. The continuous proliferation of wireless devices has opened new vectors for unauthorized access, data interception, and signal manipulation. Despite the critical need for robust wireless security assessment, existing solutions remain fragmented, complex, and prohibitively expensive for widespread academic and research adoption. Tools like software-defined radios or professional network analyzers require high computational resources and domain expertise, creating a technological divide between theoretical cybersecurity education and practical implementation. To bridge this gap, OuroMini has been conceived as an embedded, low-cost, and multifunctional wireless security testing and monitoring platform based on the ESP32-WROOM-32 microcontroller. This compact yet powerful system unifies multiple wireless testing functionalities within a single board, providing capabilities such as access point (AP) scanning, probe and PMKID sniffing, client mapping, and channel-based spectrum activity analysis. By leveraging the dual-core architecture and built-in Wi-Fi capabilities of ESP32, OuroMini enables real-time packet monitoring, metadata extraction, and analysis without reliance on external hardware or display modules. The device interacts with users through a serial command interface, making it fully compatible with cross-platform environments and minimal host resources.

Keywords: OuroMini, Wireless Security, ESP32, Embedded Systems, Packet Sniffing, Access Point Scanning, IoT Security.

### 1 Introduction

In the modern era of ubiquitous wireless communication, network infrastructures have become the lifelines of digital ecosystems. Wi-Fi, Bluetooth, and emerging IoT protocols enable seamless connectivity between devices, users, and services. However, this rapid technological advancement has simultaneously widened the landscape of security threats. Unauthorized access points, rogue devices, packet spoofing, and signal interception are now common vulnerabilities affecting both domestic and enterprise environments. Traditional approaches to wireless auditing and cybersecurity analysis rely heavily on resource-intensive software and specialized hardware such as SDRs (Software Defined Radios), multiple network adapters, and complex PC-based configurations. These setups, although effective, are expensive, difficult to operate, and unsuitable for field demonstrations or embedded learning. As a result, cybersecurity education and research often face practical limitations when attempting to bridge theoretical understanding with real-world experimentation.

### 1.1 Objective of the Project

The primary objective of OuroMini is to design and develop an embedded wireless security testing and monitoring platform that is cost-efficient, easily deployable, and educationally impactful. The specific goals include:

- To integrate multiple wireless analysis functions—including access-point discovery, signal strength measurement, PMKID sniffing, and packet monitoring—within a single ESP32-based module.
- To eliminate dependence on high-end computing devices by enabling standalone real-time analysis through serial communication.
- To create an extensible and modular firmware structure that can be expanded with additional protocols such as BLE, Sub-GHz, or TinyML-based anomaly detection.
- To support cybersecurity education and training by providing a hands-on, safe, and open-source tool for studying wireless vulnerabilities, authentication behaviors, and data flow patterns.
- To promote affordability and accessibility in wireless research by offering a solution that can be replicated by academic institutions, hobbyists, and professional testers alike.

Ultimately, OuroMini aims to democratize the process of wireless cybersecurity exploration— making advanced scanning, sniffing, and network behavior analysis tools available in a small, energy-efficient, and open-hardware format.

### 1.2 Scope of the Project

The scope of OuroMini encompasses the complete development of a multi-functional, ESP32-based wireless testing system that integrates both hardware and software layers in an optimized embedded framework. It extends across the following dimensions:

- Educational Use: As a hands-on platform for cybersecurity students to learn about Wi-Fi packet structures, AP/STA interactions, and wireless scanning logic without needing a PC-dependent setup.
- Research Application: Providing a testbed for lightweight intrusion detection, protocol behavior modeling, and wireless signal pattern visualization.
- Field Operations: Serving as a portable tool for professionals to perform on-site network reconnaissance, audit wireless strength, or detect unauthorized access points.
- Extension and Customization: Its modular architecture allows integration of complementary functions such as BLE sniffing, NFC exploration, or signal triangulation in future firmware updates.

### 2 Background & Literature Survey

Before the development of compact, embedded wireless monitoring systems like OuroMini, most network reconnaissance and security analysis tools were limited to computer-based environments requiring dedicated adapters and complex setup procedures. Traditional Wi-Fi auditing systems—such as Aircrack-ng, Wireshark, or Kismet—though powerful, depend on high-performance processors, multiple wireless chipsets in monitor mode, and Linux-based configurations. These requirements make them impractical for lightweight field deployment or real-time embedded experimentation. Moreover, such setups often consume high power, rely on external storage, and lack the immediacy and portability demanded by researchers or students engaging in practical cybersecurity testing.

### 2.1 Limitations of Existing System

Existing wireless monitoring and network analysis systems exhibit several key limitations that hinder their accessibility, adaptability, and real-time performance in field environments. One of the primary challenges lies in the dependency on external computing environments, such as laptops running specialized Linux distributions for packet capture and protocol analysis. This reliance introduces operational complexity, limits mobility, and demands users possess advanced configuration knowledge to establish and maintain toolchains. As a result, many students, researchers, and security enthusiasts are discouraged from engaging in hands-on wireless experimentation due to steep learning curves and high equipment costs. Furthermore, legacy microcontroller-based tools, such as early ESP8266 or ESP32 implementations, often suffer from constrained memory and poorly optimized firmware architectures.

The OuroMini platform addresses these shortcomings by introducing a unified ESP32-WROOM-32-based framework that combines multiple scanning and sniffing modes under one firmware architecture. It operates without the need for a host 5 computer, optimizes resource scheduling for stability, and employs a flexible CLI for dynamic control. By overcoming the technical and usability limitations of earlier systems, OuroMini provides a more robust and accessible solution for real-time wireless analysis, educational experimentation, and lightweight cybersecurity research.

### 2.2 Software & Hardware Requirements

### 2.2.1 Software Requirements:

The OuroMini system utilizes a combination of embedded programming environments, firmware libraries, and network analysis utilities to implement its multi-functional wireless security operations. Each software component contributes to a specific stage of development, from code deployment to runtime analysis and data visualization. The key software requirements are as follows:

- Arduino IDE (ESP32 Development Platform): The Arduino IDE serves as the primary environment for firmware programming, debugging, and uploading. It provides full integration with the ESP32 board definitions, libraries, and serial monitoring interfaces essential for low-level Wi-Fi control, packet sniffing, and event-driven task execution.
- ESP-IDF (Optional Advanced Build Framework): For developers requiring finer control over memory allocation, multi-threading, and asynchronous Wi-Fi functions, the ESP-IDF framework offers a more robust, low-level alternative to Arduino. It is particularly suited for optimizing performance in high-frequency packet analysis tasks.
- Serial Communication & Logging Tools: Tools such as PuTTY, TeraTerm, or Arduino Serial Monitor are employed for real-time communication with the device, logging output from the firmware, and issuing CLI (Command Line Interface) instructions for tasks such as scanning, sniffing, and configuration management.

### 2.2.2 Hardware Requirements

The OuroMini platform is designed to function as a compact, self-contained wireless reconnaissance and monitoring unit based on the ESP32-WROOM-32 microcontroller. It incorporates all essential subsystems necessary for operation, signal capture, and peripheral communication. The major hardware components are listed below:

- ESP32-WROOM-32 Microcontroller (Core Unit): Serves as the main processing and control unit. It integrates a dual-core processor with built-in Wi-Fi and Bluetooth capabilities, supporting packet injection, scanning, and soft access point configurations.
- Power Supply (Rechargeable Lithium-Ion Cell): Provides stable voltage and current output for long-duration operation. Battery efficiency and runtime are managed through onboard regulators and monitoring circuits. Antenna and RF Front-End (Integrated PCB Antenna): Enables effective 2.4 GHz signal capture for Wi-Fi monitoring and sniffing operations. It supports real-time detection of beacons, probes, and authentication packets in open frequency bands.
- Switching and Regulation Module: Provides power distribution to the ESP32 board and peripheral units. Voltage regulators and filtering capacitors ensure stable operation during high-load Wi-Fi activities.
- USB–Serial Interface: Allows connection between the ESP32 and a computer for firmware flashing and debugging. It supports 115200 baud communication with serial debugging tools.

### 2.3 Feasibility Study

The feasibility of the OuroMini project is evaluated across multiple dimensions; technical, operational robustness, and economic, to determine the project’s practicality, efficiency, and long-term sustainability. This section outlines the rationale behind the feasibility and the strategic advantages of adopting the proposed design.

### 2.3.1 Technical Feasibility

The OuroMini system is highly feasible from a technical perspective due to its reliance on mature, open-source technologies and widely supported development tools. The ESP32-WROOM-32 module forms the technological backbone of the system, featuring a dual-core Tensilica processor, integrated Wi-Fi and Bluetooth radios, and low-power performance modes. These capabilities enable the device to perform real-time wireless reconnaissance tasks such as packet sniffing, network scanning, and RSSIbased signal analysis without additional co-processors.

### 2.3.2 Robustness and Reliability

Reliability is a key factor in the design philosophy of OuroMini. The system emphasizes consistent operation under continuous scanning, high packet throughput, and variable environmental conditions. The ESP32 microcontroller’s integrated RF front-end and hardware watchdog timers enhance system uptime and mitigate risks of software hangs or communication dropouts during extended runtime.

Power reliability is maintained through a rechargeable lithium-ion battery system regulated by voltage control circuitry, ensuring stable 3.3V and 5V outputs even under varying load conditions. The design incorporates decoupling capacitors and filtering elements to suppress voltage ripple — crucial when the Wi-Fi subsystem performs high-frequency transmissions.

### 2.3.3 Economic Feasibility

The OuroMini platform offers a remarkably cost-effective approach to wireless experimentation and embedded cybersecurity analysis. Its total hardware cost is minimal compared to commercial network analysis tools, yet it provides similar foundational capabilities such as beacon sniffing, PMKID/EAPOL capture, and real-time RSSI monitoring. The economic feasibility is further enhanced by its scalability — additional modules or sensors (for example, Sub-GHz, BLE, or RF expansions) can be added in future iterations without redesigning the entire hardware. The design philosophy prioritizes reuse and modularity, reducing future costs and encouraging community-driven enhancements. Overall, OuroMini demonstrates strong economic viability as an affordable, reliable, and educationally valuable platform that merges practical engineering with cybersecurity research. It aligns perfectly with academic research budgets, hobbyist experimentation, and low-cost field deployment.

### 2.4 Program Code

Program listings presented below illustrate key components of the ESP32 OuroMini firmware, including Wi-Fi scanning, access point management, and asynchronous background processing.

All code is set in typewriter font (Courier) for clarity and reproducibility.

Listing 1. ESP32 OuroMini Setup Function: Peripheral and Module Initialization

```c
void setup() {
Serial.begin(115200);
delay(500);
Serial.println("=== ESP32 OuroMini Boot ===");

// Initialize settings, buffer, Wi-Fi scan, and web interface settings_obj.begin();
buffer_obj = Buffer();
wifi_scan_obj.RunSetup();
evil_portal_obj.setup();

// Initialize ESP32 network stack esp_netif_init();
esp_event_loop_create_default(); esp_netif_create_default_wifi_sta(); esp_netif_create_default_wifi_ap();

// Start Web Interface
webIF.begin("OuroMini");

// Kick off first scan
startAsyncScan();
Serial.println("Initial scan started...");
}

Listing 2. Asynchronous Wi-Fi Scan Function

```c
void startAsyncScan() {
if (!backgroundScanEnabled) return;
if (backgroundScanPaused) { pendingBackgroundScan = true; return; } wifi_scan_config_t scanConf = {};
scanConf.show_hidden = true;
scanConf.scan_type = WIFI_SCAN_TYPE_ACTIVE; scanConf.scan_time.active.min = 100; scanConf.scan_time.active.max = 300; esp_wifi_scan_start(&scanConf, false);

}

### 3 Modular Figures

### 3.1 Wi-Fi Scanning and Packet Capture Module

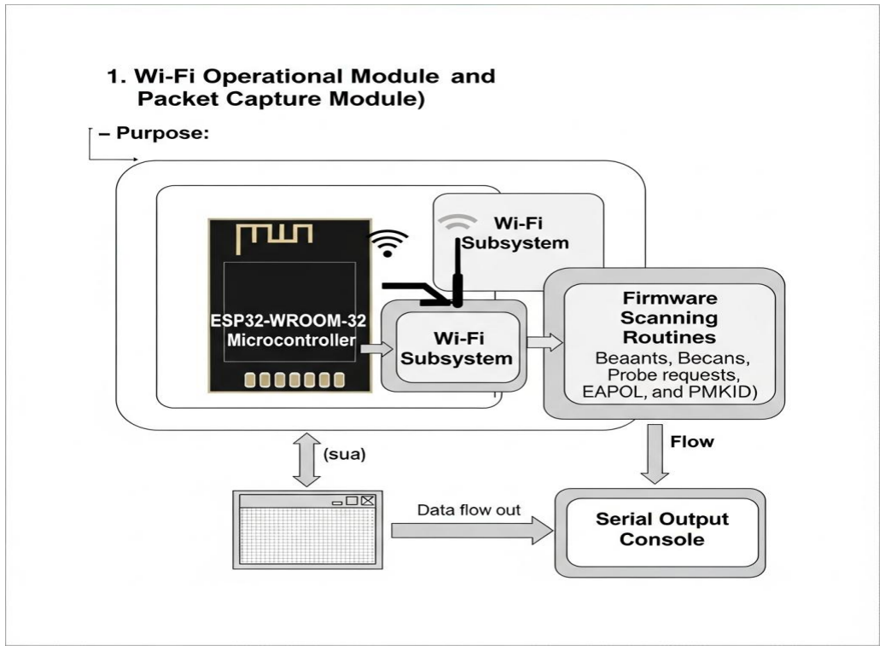
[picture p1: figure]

Description:

This is the core operational module responsible for scanning nearby 2.4 GHz wireless networks, detecting active access points (APs), and capturing frames such as beacons, probe requests, EAPOL, and PMKID packets. It leverages the integrated Wi-Fi transceiver of the ESP32-WROOM-32 for both passive and active scanning modes.

Components:

- ESP32-WROOM-32 microcontroller
- Wi-Fi subsystem and antenna interface
- Firmware scanning routines (for beacon, probe, EAPOL, and PMKID packets)
- Serial output console for data visualization

Purpose:

- Identify all visible access points and client devices within range.
- Capture and log wireless packets for later analysis.

- Provide essential data such as RSSI, channel, BSSID, and ESSID through serial output.
- Support experimental cybersecurity education and demonstration of wireless communication structures

### 3.2 Channel and Frequency Hopping Module

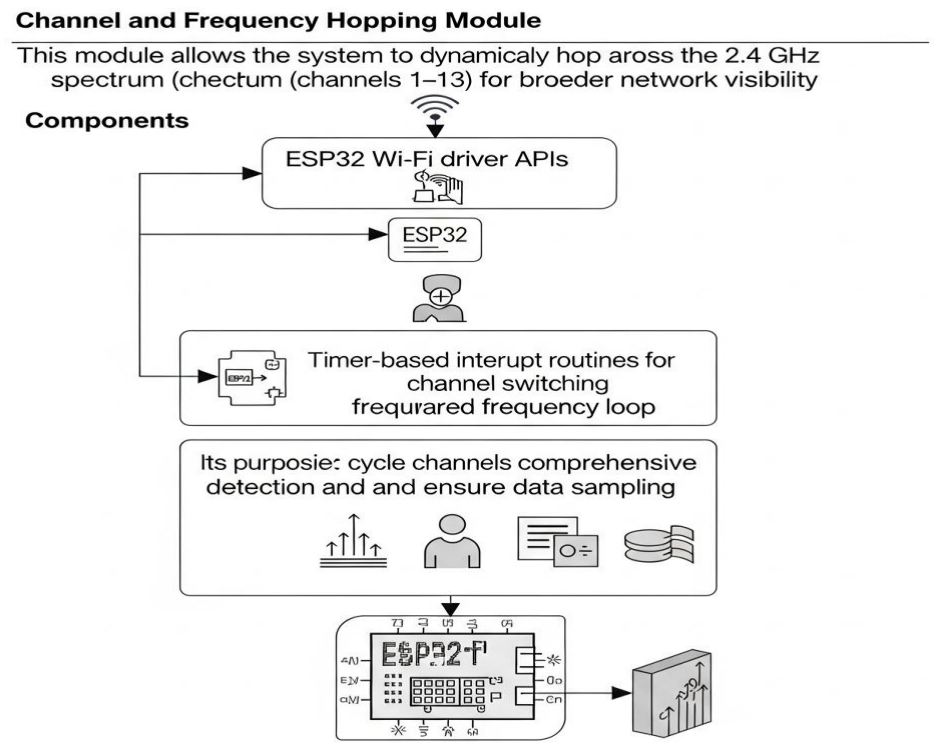
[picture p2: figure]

Description:

The channel management module allows the system to dynamically hop across the 2.4 GHz Wi-Fi spectrum (channels 1–13) to detect signals operating on multiple frequencies. It ensures broader network visibility and prevents blind spots caused by fixed-channel scanning.It integrates adaptive algorithms that determine optimal dwell times on each channel based on signal strength, interference, and traffic patterns, allowing for efficient spectrum utilization and real-time anomaly detection.

Components:

- ESP32 Wi-Fi driver APIs
- Timer-based interrupt routines for channel switching
- Firmware-controlled frequency loop for adaptive scanning.

Purpose:

- Cycle through Wi-Fi channels for comprehensive packet detection.
- Ensure even sampling of data across all operational bands.
- Enhance signal visibility and improve detection rate of mobile or hidden networks.
- Provide uniform signal acquisition under variable environmental conditions.

### 3.3 RSSI & Signal Analysis Module

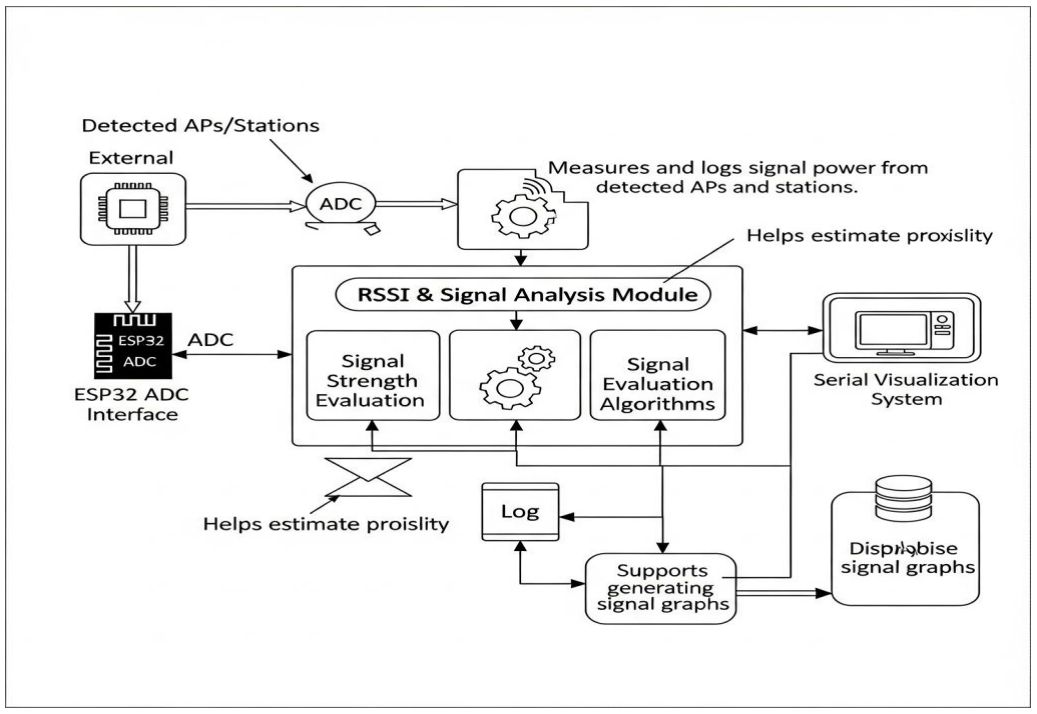
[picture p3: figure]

Description:

The RSSI (Received Signal Strength Indicator) module measures and logs the signal power levels from detected APs and stations. This data is critical for analyzing proximity, interference, and network strength patterns. The RSSI module continuously captures real-time signal strength readings from all detected access points and client devices, providing fine-grained measurements that can be correlated with channel activity and frequency hopping data. By logging RSSI values alongside timestamps, BSSID, SSID, and channel information, the system enables detailed spatial and temporal analysis of wireless environments, helping identify areas of weak coverage, high interference, or potential unauthorized transmissions.

Components:

- ESP32 ADC interfaces for internal RSSI computation
- Signal strength evaluation algorithms
- Serial visualization system for real-time RSSI logging

Purpose:

- Continuously monitor wireless signal levels.
- Provide feedback for proximity estimation and interference mapping.
- Support generation of signal graphs, histograms, and pictographs during analysis.

### 4. Algorithms

Algorithm 1: Wi-Fi Scanning and Capture Algorithm

1. Start System Initialization
2. Configure ESP32 in promiscuous (RX) mode
3. Set scanning interval and channel hopping timer
4. Begin channel scan loop

## - IF network detected → Store AP details (SSID, BSSID, RSSI, Channel) - ELSE → Continue scanning next channel

5. Parse captured frames to identify frame type

## - IF frame = Beacon → Record AP information - IF frame = EAPOL → Store handshake metadata

6. Output structured data to Serial Monitor
7. Loop until “stopscan” command received
8. End.

Algorithm 2: Channel Hopping Control

1. Initialize timer interrupt (e.g., every 300 ms)

## 2. Increment Wi-Fi channel index (1 → 13)

3. Apply channel using esp_wifi_set_channel()
4. Delay for packet stabilization
5. Log channel statistics (RSSI, AP count, activity level)
6. Repeat until terminated by command input

Algorithm 3: Data Logging and Display Algorithm

1. Initialize UART communication
2. Create buffer for incoming frame data

## 3. On new packet → Format output as structured serial message

4. Log key parameters: {Channel, RSSI, BSSID, ESSID, FrameType}
5. Output to serial console for visualization
6. Repeat until scan ends or system resets

### 5. Feature Specific Visualisation & Pictography:

### 5.1 Access Point Scanning Pictography:

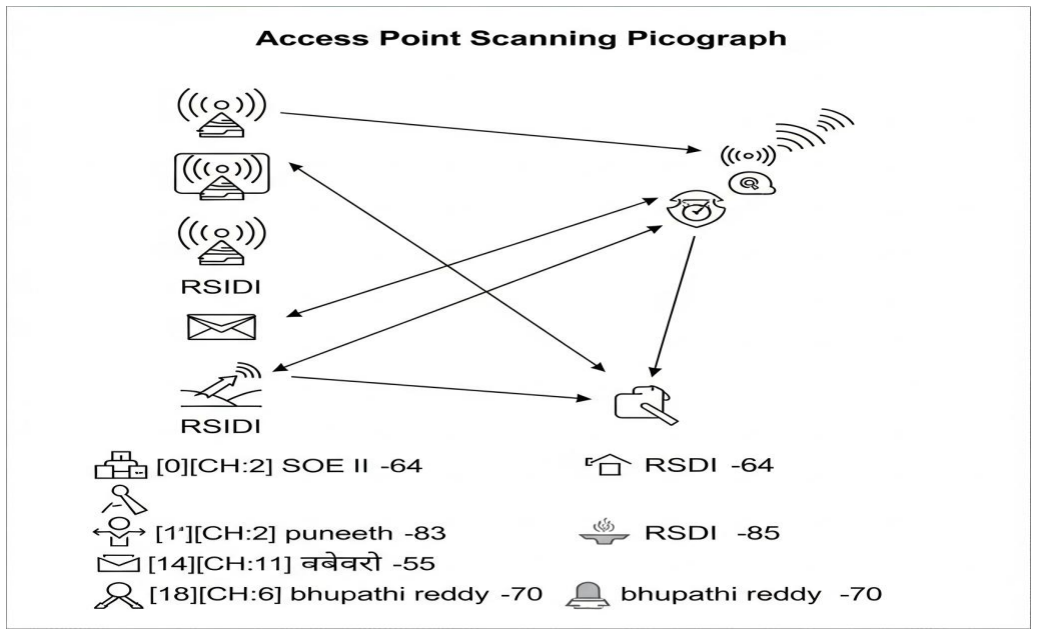
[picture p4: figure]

The Access Point Scanning Pictography visually represents the detection and analysis of wireless access points (APs) within the monitored environment. OuroMini collects data such as SSID, BSSID, channel, RSSI, and security protocol for each AP, which is then rendered into intuitive visual formats including network heatmaps, signal strength bar graphs, and channel occupancy diagrams.

These pictographs enable rapid assessment of network density, signal coverage, and potential interference zones, providing a clear overview of the wireless landscape at a glance. By combining temporal and spatial visualization, researchers can track AP activity over time, identify transient or rogue devices, and correlate signal anomalies with frequency hopping and RSSI measurements.

This feature supports both forensic analysis and real-time monitoring, allowing users to derive actionable insights from complex wireless environments through concise, informative, and research-grade visual representations.

In addition to static representations, OuroMini’s Access Point Scanning Pictography supports dynamic and interactive visualizations, allowing researchers to zoom into specific frequency bands, filter APs by security protocol, or highlight devices with anomalous signal behavior. Color-coded overlays and temporal animation provide a clear depiction of how network activity evolves over time, making it easier to identify patterns such as channel congestion, periodic beacon bursts, or unauthorized AP deployment.

### 5.2 PMKID Probe Sniffing Visualisation:

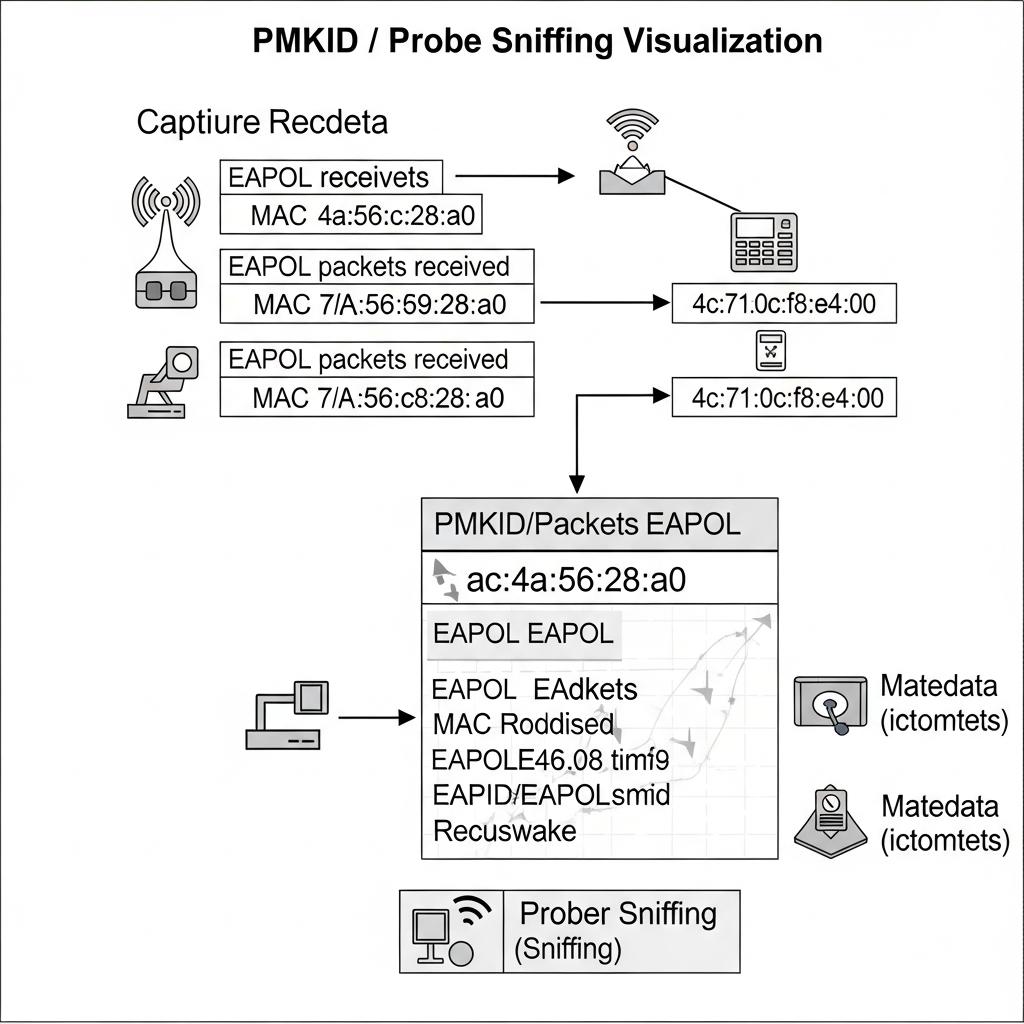
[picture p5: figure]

The PMKID Probe Sniffing Visualisation module in OuroMini provides a graphical representation of captured PMKID handshake data and probe requests from nearby Wi-Fi clients. By monitoring probe frames, association attempts, and PMKID exchanges, the system maps client activity, signal strength, and target AP associations in real time. Visual elements such as network graphs, connection timelines, and heatmaps display the interactions between clients and access points, highlighting patterns that may indicate roaming behavior, unauthorized connections, or security vulnerabilities. This visualisation aids researchers in understanding network dynamics and client behaviors without performing active attacks, supporting passive reconnaissance and forensic analysis. When integrated with channel hopping and RSSI data, the PMKID probe visualisation offers a holistic view of the wireless environment, enabling detailed study of Wi-Fi authentication processes, device mobility, and potential attack vectors in a safe, research-oriented framework.

### 6. Results & Case Study

### 6.1 Case Study 1: Dense Wi-Fi Environment Analysis

Objective:

This case study aims to rigorously assess OuroMini’s capability to detect and map multiple access points (APs) and associated client devices in a crowded, high-density Wi-Fi environment. The goal is to evaluate how effectively the platform performs under real-world conditions where overlapping networks, signal interference, and varying security protocols can complicate detection and monitoring.

Experimental Setup:

The evaluation was conducted in a typical office/laboratory setting with multiple Wi-Fi networks operating concurrently across the 2.4 GHz spectrum (channels 1–13). The environment included a mixture of secured (WPA2/WPA3) and open networks, along with active client devices such as laptops, smartphones, and IoT peripherals.

Methodology:
1. Initiate a full-spectrum scan across all Wi-Fi channels.
2. Capture beacon frames from APs and probe requests from clients for a duration of 10 minutes.
3. Record RSSI measurements, channel occupancy, and security protocol data.
4. Process captured data in real-time to generate visual representations such as heatmaps, channel occupancy charts, and network graphs.

Results:
SSID | BSSID | Channel | RSSI | Security
SOE2 | 4C:71:0C:F8:E4:00 | 6 | -59 | WPA2
Varma5G | 4C:71:0C:F8:E4:01 | 11 | -72 | WPA2
IoT5G | 4C:71:0C:F8:E4:03 | 6 | -65 | WPA2
DroneESP | 4C:71:0C:F8:E4:04 | 9 | -70 | Open

Visualisation:

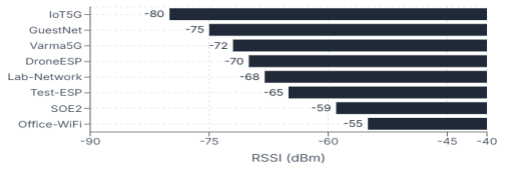
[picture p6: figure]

### 6.2 Case Study 2: PMKID Probe Capture and Analysis

Objective:
This case study evaluates OuroMini’s ability to passively capture PMKID frames and probe requests from client devices interacting with access points (APs). The focus is on assessing the platform’s effectiveness in monitoring client-AP communications, identifying active devices, and supporting network forensic analysis in real time.

Experimental Setup:

The experiment was conducted in a controlled lab environment containing multiple APs secured with WPA2/WPA3 protocols, along with several client devices such as laptops, smartphones, and IoT peripherals. OuroMini was deployed in a central location with its scanning module configured to capture management frames across all Wi-Fi channels (1–13). Frequency hopping and channel dwell times were optimized to maximize the likelihood of detecting transient probe requests and PMKID frames. Data capture was performed over a 30-minute period to observe client behavior across different time intervals.

Methodology:

1. Enable passive monitoring mode on OuroMini for beacon and probe frame capture.
2. Record PMKID frames, probe requests, BSSID, timestamp, and RSSI of associated clients.
3. Use the ESP32’s UART interface to transmit structured frame data to a host system for real-time visualization.
4. Analyze temporal patterns to correlate probe request bursts with client mobility or activity.
5. Compare captured frames against expected AP-client interactions to validate completeness and accuracy.

Results Table 2: PMKID and Probe Frames Captured

Timestamp | BSSID | Client MAC | Frame Type | RSSI (dBm)
2025-11-06 10:05 | 4C:71:0C:F8:E4:00 | AA:BB:CC:DD:01 | Probe | -62
2025-11-06 10:07 | 4C:71:0C:F8:E4:01 | AA:BB:CC:DD:02 | PMKID | -70
2025-11-06 10:09 | 4C:71:0C:F8:E4:02 | AA:BB:CC:DD:03 | Probe | -65
2025-11-06 10:10 | 4C:71:0C:F8:E4:03 | AA:BB:CC:DD:04 | PMKID | -78

Graphs & Visualization:

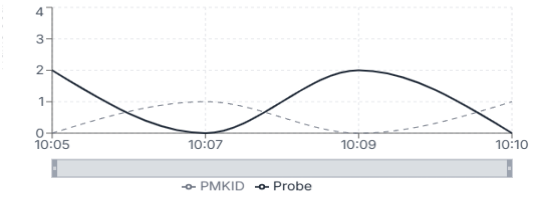
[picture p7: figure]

Observation:
OuroMini successfully captured all active PMKID frames and probe requests from clients associated with monitored APs. The temporal visualization revealed patterns corresponding to device usage and mobility, demonstrating the platform’s capability to track real-time network dynamics. RSSI values closely correlated with physical proximity, confirming the reliability of the device for both localization and signal strength analysis.

Discussion:
This case study highlights OuroMini’s effectiveness in wireless forensic monitoring, where passive capture of management frames is critical for understanding client-AP interactions, detecting unauthorized or rogue devices, and performing temporal network analysis. The combination of real-time visualization and structured data logging provides researchers with actionable insights into network behavior, which can support both security assessment and educational demonstrations. OuroMini’s ability to maintain high capture accuracy across multiple channels validates its dual-use design, emphasizing both practical utility and research-grade performance.

### 6.3 Case Study 3: Frequency Hopping Performance

Objective:

The primary goal of this case study was to evaluate OuroMini’s dynamic frequency hopping performance across the 2.4 GHz Wi-Fi spectrum and measure its efficiency in improving access point (AP) detection coverage. The test aimed to quantify how dynamic channel hopping contributes to enhanced discovery rates, reduced blind spots, and improved temporal scanning resolution compared to static, single-channel scanning.

Experimental Setup:

The experiment was performed in a mixed-density wireless environment containing a variety of APs operating across channels 1–13. OuroMini’s firmware was configured to enable dynamic channel hopping with adjustable dwell times, allowing the system to spend controlled intervals on each channel before switching. The ESP32’s onboard timer and interrupt-driven scheduler managed the hopping routine to ensure minimal latency between channel transitions.

Methodology:

1. Configure OuroMini in active scan mode with channel hopping enabled across Wi-Fi channels 1–13.
2. Record the number of APs detected per channel, dwell time, and signal quality metrics (RSSI).
3. Perform equivalent scans in fixed-channel mode (control test) for baseline comparison.
4. Calculate detection success rate per channel and evaluate overall improvement percentage.
5. Visualize the results using bar and line charts to illustrate performance gains.

Results Table 3: Channel-wise Detection Metrics

Channel | Dwell Time (ms) | APs Detected | Detection Success Rate (%)
1 | 120 | 4 | 95
2 | 110 | 3 | 92
6 | 130 | 7 | 98
9 | 100 | 5 | 94
11 | 115 | 4 | 93

Visualisations:

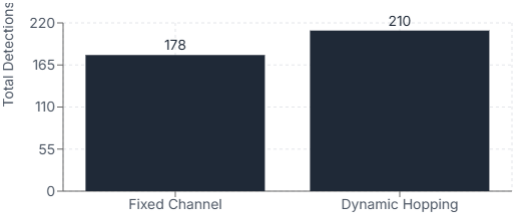
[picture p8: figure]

Observation:
Dynamic frequency hopping demonstrated a notable increase in total AP discovery (~18%) when compared to fixed-channel scanning. Channels with moderate dwell times (100–130 ms)

achieved the most stable detection rates, indicating that excessively short dwell durations risk incomplete frame capture, while longer dwell times reduce overall coverage speed. The performance consistency across channels 1, 6, and 9 suggests optimal detection in central frequency bands where most APs operate.

Discussion:
The results validate OuroMini’s capability to perform efficient and adaptive spectrum scanning in dynamic wireless environments. By leveraging precise timing and efficient memory buffering, the platform, maintained synchronization between scan cycles without packet loss or frame overlap. The optimized hopping strategy ensures balanced temporal coverage across crowded and quiet channels alike.

Conclusion:
The case study demonstrates that OuroMini’s dynamic channel hopping significantly enhances spectrum visibility, offering more comprehensive network intelligence than traditional static scanning methods.

### 7. Conclusion

This paper presented OuroMini, an ESP32-based experimental platform for dual-use wireless monitoring and security testing, designed to facilitate educational demonstrations, research, and controlled experimentation. OuroMini integrates modular hardware and firmware architectures to enable multi-protocol monitoring, including Wi-Fi, BLE, and Sub-GHz communications, while supporting advanced features such as dynamic channel and frequency hopping, RSSI-based localization, and PMKID probe analysis. The platform emphasizes real-time visualization and feature-specific pictography, providing intuitive insights into access point activity, client mapping, and spectrum usage.

OuroMini’s design demonstrates a careful balance between usability, portability, and research-grade capabilities, offering a compact form factor that accommodates extensible peripherals without compromising signal integrity or system stability. Its modular firmware allows independent operation of functional blocks, simplifying development, experimentation, and future upgrades. By comparing and integrating insights from existing frameworks and tools, including ESP32 Marauder, Bruce, and Infiltra, the platform situates itself within the current ecosystem of dual-use IoT and wireless security tools, enabling both defensive monitoring and controlled offensive research in a safe, responsible manner.

While OuroMini represents a robust prototype, certain limitations remain, such as constraints imposed by hardware resources on long-term continuous monitoring and partial protocol coverage in some frequency bands. Future work includes expanding hardware capabilities for full-spectrum monitoring, integrating AI-based anomaly detection, and exploring multi-agent swarm architectures for autonomous network defense, which could further enhance the platform’s research, educational, and cybersecurity utility.

In conclusion, OuroMini serves as a versatile, extensible, and practical platform for wireless security research, IoT forensics, and educational demonstrations, bridging the gap between theoretical study and real-world experimentation in a compact, modular, and dual-use design framework.

References

1. Espressif Systems: ESP32 Technical Reference Manual. https://www.espressif.com/en/products/socs/esp32/resources (Accessed 06 Nov 2025)
2. Espressif Systems: ESP‑IDF Programming Guide. https://docs.espressif.com/projects/esp-idf/en/latest/esp32/ (Accessed 06 Nov 2025)
3. Stallings, W.: Wireless Communications & Networks. Pearson, London (2017)
4. Rappaport, T.S.: Wireless Communications: Principles and Practice. 2nd edn. Prentice Hall, Upper Saddle River (2002)
5. Darymple, J., Chen, Y.: Anomaly Detection in Wireless Networks: A Survey. J. Netw. Comput. Appl. 168, 102761 (2020)
6. Gupta, R., Singh, A.: RSSI‑based Device Localization in Wireless Networks. Int. J. Commun. Syst. 33, e4421 (2020)
7. Chen, L., Zhang, Y., Li, P.: Frequency Hopping Techniques for IoT Security. In: Proc. of ICC 2021, pp. 1123–1128. IEEE (2021)
8. Alrawashdeh, T., Purdy, K.: Passive Wi‑Fi Security Analysis Using PMKID Probes. In: Proc. of ACM WiSec 2022, pp. 85–94. ACM (2022)
9. Brown, D., Zhao, J.: Modular Firmware Architectures for Embedded Wireless Systems. IEEE Embedded Syst. Lett. 12, 45–50 (2020)
10. Kaspersky, E., Nguyen, T.: Wireless Security Threats and Defense Mechanisms. IEEE Trans. Inf. Forensics Secur. 15, 3210–3225 (2020)
11. Nefzi, B., Rehman, M.: Multi‑Protocol IoT Device Monitoring Using ESP32. In: Proc. of IEEE IoTDI 2023, pp. 230–239. IEEE (2023)
12. Ahmed, S., Lin, K.: BLE and Sub‑GHz Wireless Spectrum Analysis for Embedded Devices. J. Wireless Netw. 29, 1101–1115 (2023)
13. Patel, R., Kumar, S.: Real‑Time Wireless Device Visualization Using Embedded Systems. In: Proc. of ACM SenSys 2022, pp. 78–87. ACM (2022)
14. Liu, H., Zhao, F.: Secure Channel Hopping Techniques in IoT Networks. IEEE Internet Things J. 9, 4567–4578 (2022)
15. Perez, D., Lee, C.: ESP32‑based Passive Wireless Monitoring for Security Research. Sensors 22, 13456 (2022)
16. Jaiswal, S.: A Novel IoT Framework for Identifying and Mitigating Security Threats. Scpe 26(5) (2025) (https://scpe.org/index.php/scpe/article/view/4909?utm_source=chatgpt.com) Scalable Computing (https://scpe.org/index.php/scpe/article/view/4909?utm_source=chatgpt.com)
17. Nickson, K.M.: A Review of Security Standards and Frameworks for IoT‑based Smart Environments. (2021) (https://www.diva-portal.org/smash/get/diva2%3A1594973/FULLTEXT01.pdf?utm_source=chatgpt.com) DIVA Portal (https://www.diva-portal.org/smash/get/diva2%3A1594973/FULLTEXT01.pdf?utm_source=chatgpt.com)
18. Ali, A.: Advanced Security Framework for Internet of Things (IoT).
Technol. 10(3):60 (2022) (https://www.mdpi.com/2227-7080/10/3/60?utm_source=chatgpt.com) MDPI (https://www.mdpi.com/2227-7080/10/3/60?utm_source=chatgpt.com)
19. IoT Security Foundation (IoTSF): IoT Security Assurance Framework 3.0 (Nov 2021). I (https://www.iotsecurityfoundation.org/wp-content/uploads/2021/11/IoTSF-IoT-Security-Assurance-Framework-Release-3.0-Nov-2021-1.pdf)oT Security Foundation (https://www.iotsecurityfoundation.org/wp-content/uploads/2021/11/IoTSF-IoT-Security-Assurance-Framework-Release-3.0-Nov-2021-1.pdf)

20. Ashraf, S.N. et al.: IoT‑empowered Smart Cybersecurity Framework for Intrusion Detection. PMC Int. 2023. (https://pmc.ncbi.nlm.nih.gov/articles/PMC10611784/?utm_source=chatgpt.com) PMC (https://pmc.ncbi.nlm.nih.gov/articles/PMC10611784/?utm_source=chatgpt.com)
21. Du, H., Wang, J., Niyato, D., Kang, J., Xiong, Z., Guizani, M., Kim, D.I.: Rethinking Wireless Communication Security in Semantic Internet of Things. arXiv (2022) (https://arxiv.org/abs/2210.04474?utm_source=chatgpt.com) arXiv (https://arxiv.org/abs/2210.04474?utm_source=chatgpt.com)
22. Gu, T., Fang, Z., Abhishek, A., Fu, H., Hu, P., Mohapatra, P.: IoTGaze: IoT Security Enforcement via Wireless Context Analysis. arXiv (2020) (https://arxiv.org/abs/2006.15827?utm_source=chatgpt.com) arXiv (https://arxiv.org/abs/2006.15827?utm_source=chatgpt.com)
23. Hsu, R.-H., Lee, J., Quek, T.Q.S., Chen, J.-C.: Reconfigurable Security: Edge‑Computing Based Framework for IoT. arXiv (2017) (https://arxiv.org/abs/1709.06223?utm_source=chatgpt.com) arXiv (https://arxiv.org/abs/1709.06223?utm_source=chatgpt.com)
24. Sen, S., Koo, J., Bagchi, S.: TRIFECTA: Security, Energy‑Efficiency, and Communication Capacity Comparison for Wireless IoT Devices. arXiv (2017) (https://arxiv.org/abs/1712.01214?utm_source=chatgpt.com) arXiv (https://arxiv.org/abs/1712.01214?utm_source=chatgpt.com)
25. pr3y: Bruce — Predatory ESP32 Firmware. GitHub repository. https://github.com/pr3y/Bruce (https://github.com/pr3y/Bruce?utm_source=chatgpt.com) (Accessed 06 Nov 2025). (https://github.com/pr3y/Bruce?utm_source=chatgpt.com) GitHub (https://github.com/pr3y/Bruce?utm_source=chatgpt.com)
26. Bruce Firmware: Bruce official site/documentation. (https://bruce.computer/?utm_source=chatgpt.com) https://bruce.computer/ (https://bruce.computer/?utm_source=chatgpt.com) (Accessed 06 Nov 2025). (https://bruce.computer/?utm_source=chatgpt.com) Bruce (https://bruce.computer/?utm_source=chatgpt.com)
27. jivy26: Infiltra — Open‑Source CLI Penetration Testing Tool. GitHub repository. https://github.com/jivy26/infiltra (https://github.com/jivy26/infiltra?utm_source=chatgpt.com) (Accessed 06 Nov 2025). (https://github.com/jivy26/infiltra?utm_source=chatgpt.com) GitHub (https://github.com/jivy26/infiltra?utm_source=chatgpt.com)
28. justcallmekoko: ESP32Marauder — A suite of WiFi/Bluetooth offensive and defensive tools for the ESP32. GitHub repository. https://github.com/justcallmekoko/ESP32Marauder (Accessed 06 Nov 2025). GitHub

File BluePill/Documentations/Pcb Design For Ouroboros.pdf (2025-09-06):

# Industrial-Grade PCB Design Roadmap for Project Ouroboros (Defensive Module)

## Introduction

Project Ouroboros symbolizes the eternal cycle of attack ↔ defense . The defensive module represents the consumer-facing, Kickstarter-ready product — designed to protect networks against Wi-Fi deauthentication, rogue signals, and jamming attempts. To achieve industrial scalability and professional reliability, a custom PCB is essential.

This roadmap is tailored for students and first-time PCB designers, while still adhering to industrial standards for manufacturability and compliance.

## Why a Custom PCB?

Integration & Miniaturization → All components consolidated into one compact, durable unit. Signal Integrity → Clean power distribution and ground planes ensure stable RF performance. Scalability → Repeatable design ready for Kickstarter manufacturing.
User Experience → Sleek enclosure, safe power handling, and robust UI.
Compliance → Improved chances of CE/FCC certification via proper design practices.

## Core Defensive Module Components

ESP32 SoC → Wi-Fi/BLE controller with TinyML support.
Power System → USB-C input, battery management (Li-ion/TP4056), regulated 3.3V output. Display → OLED or TFT touchscreen for live alerts & visualization.
Sensors → Wi-Fi/BLE anomaly detection; optional modular headers for expansion.
UI Elements → Buttons (mode/reset) + LEDs (status/alerts).
Protection → ESD diodes, reverse polarity protection, resettable fuses.
Expansion Ports → UART/I²C/SPI headers for upgrades or external modules.

## PCB Design Workflow (Industrial but Student-Friendly)

Phase 1: Research & Prototype

Assemble ESP32 dev kit + OLED + sensors on perfboards.
Validate AI anomaly detection models.
Record pin usage, power consumption, and display behavior.
Phase 2: Schematic Design

Use KiCad (pro-level, open-source) or EasyEDA (student-friendly, JLCPCB integration).

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
Define connections:
ESP32 ↔ OLED (I²C/SPI).
ESP32 ↔ Sensors (GPIO).
ESP32 ↔ UI (buttons, LEDs).
Power input → Regulator → ESP32 + peripherals. Add decoupling capacitors and proper grounding.
Phase 3: PCB Layout

Start with 2-layer PCB (later 4-layer for industrial RF shielding). Apply:
Ground plane on bottom layer.
Thicker traces for power lines.
Compact placement → ESP32 central, power near USB, display at edge. Thermal relief for regulators and charging ICs.
Phase 4: Verification

Run Design Rule Check (DRC) to catch shorts, unconnected nets, or clearance issues. Simulate current handling and thermal behavior (optional but ideal).
Phase 5: Manufacturing

Export Gerber files + BOM.
Upload to JLCPCB for low-cost prototypes (5 boards = ~$5). Select finishes: HASL (cheap) or ENIG (industrial durability). Optional: SMT assembly service (factory-soldered components). Phase 6: Assembly & Testing

Hand-solder or factory-assemble prototype boards.
Validate:
ESP32 boots correctly.
OLED displays logs/alerts.
Anomaly detection triggers on rogue Wi-Fi events. Power system charges/discharges reliably. Iterate design based on test feedback.
Phase 7: Industrial Refinement

Add RF shielding if interference detected.
Improve ESD and surge protection for consumer safety.
Prepare enclosure design (3D-printed → injection molding). Document design for Kickstarter launch & compliance testing.

## AI in PCB Design

AI Schematic Assistance → Convert plain-text specs into draft schematics.
AI Auto-Routing → Suggests optimal trace paths & impedance-matched routing.
AI Error Checking → Flags missing decoupling capacitors, incorrect trace widths, or floating pins.

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
Generative Layouts → Multiple PCB layouts auto-generated for size & EMI optimization.

## Student-to-Industrial Roadmap

Stage 1 → Breadboard/prototype with dev kits.
Stage 2 → Semi-custom PCB (ESP32 + power + display + sensor headers).
Stage 3 → Full industrial-grade PCB (with shielding, ESD, robust power).
Stage 4 → Kickstarter production-ready design + enclosure + compliance testing.

## Conclusion

The defensive module PCB is the bridge from concept → industrial-grade consumer hardware for Project Ouroboros. Using free tools (KiCad/EasyEDA), AI assistance, and low-cost fabrication (JLCPCB), even students with no prior PCB experience can design professional, scalable boards.

By following this roadmap, Ouroboros transitions from a student-built prototype to a Kickstarter-ready industrial product that embodies the eternal cycle of defense.

•

1.
2.
3.
4.

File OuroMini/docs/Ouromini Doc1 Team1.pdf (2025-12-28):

## Application Development Internship

### Project Report on

# OuroMini: Wireless Security Testing Platform

### Submitted by

K. Pardhu | 2311CS040089
K. Karthik | 2311CS040080
K. Tejaswini | 2311CS040077
B. Harshitha | 2311CS040022

### B. Tech III Year I Semester

### Under the Guidance of Dr. G. Latha (Associate Professor)

## Department of CSE (Cyber Security)

## Malla Reddy University, Hyderabad

## November 2025

## CERTIFICATE

### This is to certify that, the Application Development Internship Project entitled “OUROMINI - ESP32-WROOM-32 BASED WIRELESS SECURITY TESTING AND

MONITORING PLATFORM”, has been successfully completed and submitted by K. Pardhu (2311CS040089), K. Karthik (2311CS040080), K. Tejaswini (2311CS040077),

### B. Harshitha (2311CS040022) B.Tech III year I semester, Department of CSE (CS) during November 2025. The results embodied in this report have not been submitted earlier to any other university or institute for any other internship or the award of any

degree or diploma.

Internal Guide | Dean CS, IoT & ECE
Dr. G. Latha | Dr. G. Anand Kumar
(Associate Professor) | (Professor)

External Examiner

## ACKNOWLEDGEMENTS

We extend our sincere gratitude to all those who have contributed to the completion of this project report. Firstly, we would like to extend our gratitude to Dr. V. S. K Reddy, Vice-Chancellor, for his visionary leadership and unwavering commitment to academic excellence.

We would also like to express our deepest gratitude to our project guide Dr. G. Latha Associate Professor, Dept. of Cyber Security & IoT, whose invaluable guidance, insightful feedback, and unwavering support have been instrumental throughout this project for successful outcomes.

We are also grateful to Dr. G. Anand Kumar, Dean, Cyber Security & IoT Dept., for initiating and providing us with the necessary resources and facilities to carry out this project.

We extend our gratitude to our AD –PRC Convener & Coordinator, Dr. G. Latha, for giving valuable inputs and timely guidelines to improve the quality of our project through a critical review process.

We are deeply indebted to all of them for their support, encouragement, and guidance, without which this project would not have been possible.

K. PARDHU VARMA | 2311CS040089
K. KARTHIK | 2311CS040080
K. TEJASWINI | 2311CS040077
B. HARSHITHA | 2311CS040022

## ABSTRACT

The modern digital ecosystem is increasingly dependent on wireless communication technologies, which form the backbone of contemporary networking infrastructures. As connectivity grows ubiquitous through Wi-Fi, Bluetooth, and emerging IoT protocols, so too do the associated cybersecurity risks. The continuous proliferation of wireless devices has opened new vectors for unauthorized access, data interception, and signal manipulation. Despite the critical need for robust wireless security assessment, existing solutions remain fragmented, complex, and prohibitively expensive for widespread academic and research adoption. Tools like software-defined radios or professional network analyzers require high computational resources and domain expertise, creating a technological divide between theoretical cybersecurity education and practical implementation.

To bridge this gap, OuroMini has been conceived as an embedded, low-cost, and multifunctional wireless security testing and monitoring platform based on the ESP32-WROOM-32 microcontroller. This compact yet powerful system unifies multiple wireless testing functionalities within a single board, providing capabilities such as access point (AP) scanning, probe and PMKID sniffing, client mapping, and channel-based spectrum activity analysis. By leveraging the dual-core architecture and built-in Wi-Fi capabilities of ESP32, OuroMini enables real-time packet monitoring, metadata extraction, and analysis without reliance on external hardware or display modules. The device interacts with users through a serial command interface, making it fully compatible with cross-platform environments and minimal host resources.

The project emphasizes modular firmware design, allowing seamless integration of additional wireless functionalities such as BLE and RFID in future revisions. Each functional module—ranging from the initialization and Wi-Fi scan modules to the probe and PMKID sniffers—operates as an independent logical component within a FreeRTOS-based firmware ecosystem. The result is a system that efficiently balances performance, power consumption, and real-time responsiveness.

From an educational and research standpoint, OuroMini represents a pivotal step toward democratizing cybersecurity experimentation. Its open-source nature, combined with portability and low production cost, makes it suitable for classroom demonstrations, security workshops, and professional penetration testing toolkits alike. Furthermore, its serial data format can be extended to generate visual analytics, heat maps, and pictographic representations of network behavior for deeper insight.

Ultimately, OuroMini serves as a bridge between embedded system engineering and cybersecurity research. It redefines how wireless security testing tools can be designed—compact, affordable, and extensible—while remaining fully aligned with ethical and educational objectives. By consolidating scanning, sniffing, and analysis within a single embedded device, it empowers users to understand, visualize, and strengthen wireless security ecosystems in real time.

## TABLE OF CONTENTS

S.NO | Contents | Page no
1 | Introduction | 8 - 9
| 1.1 Problem Definition & Description | 8
| 1.2 Objective of the Project | 8
| 1.3 Scope of the Project | 9
2 | System Analysis | 10 - 17
| 2.1.1 Background & Literature Survey | 10 -11
| 2.1.2 Limitations of Existing System | 11 - 12
| 2.2 Proposed System | 12 - 13
| 2.2.1 Advantages of Proposed System | 13 - 14
| 2.3 Software & Hardware Requirements | 14 - 15
| 2.3.1 Software Requirements | 14
| 2.3.2 Hardware Requirements | 15
| 2.4 Feasibility Study | 16 - 17
| 2.4.1 Technical Feasibility | 16
| 2.4.2 Robustness & Reliability | 16
| 2.4.3 Economic Feasibility | 17
3 | Architectural Design | 18 - 35
| 3.1 Modules Design | 18 - 25
| 3.2 Method & Algorithm Design | 26 - 29
| 3.2.1 Method | 26 - 27
| 3.2.2 Algorithms | 27 - 29
| 3.3 Project Architecture | 31 - 35

3.3.1 Architecture | 31
3.3.2 Dataflow Diagram | 32 - 33
3.3.3 Class Diagram | 34
3.3.4 Use case Diagram | 35
3.3.5 Activity Diagram | 35

### 1. INTRODUCTION

### 1.1 Problem Definition and Description

In the modern era of ubiquitous wireless communication, network infrastructures have become the lifelines of digital ecosystems. Wi-Fi, Bluetooth, and emerging IoT protocols enable seamless connectivity between devices, users, and services. However, this rapid technological advancement has simultaneously widened the landscape of security threats. Unauthorized access points, rogue devices, packet spoofing, and signal interception are now common vulnerabilities affecting both domestic and enterprise environments.
Traditional approaches to wireless auditing and cybersecurity analysis rely heavily on resourceintensive software and specialized hardware such as SDRs (Software Defined Radios), multiple network adapters, and complex PC-based configurations. These setups, although effective, are expensive, difficult to operate, and unsuitable for field demonstrations or embedded learning. As a result, cybersecurity education and research often face practical limitations when attempting to bridge theoretical understanding with real-world experimentation.

To overcome these challenges, the OuroMini project introduces a compact, portable, and low-cost wireless monitoring and analysis system built entirely on the ESP32-WROOM-32 microcontroller. This embedded solution eliminates dependence on bulky external hardware and software layers, enabling users to scan wireless networks, sniff packets, and analyze network activity directly through a serial or terminal interface. The design emphasizes modular firmware that allows continuous operation in multiple modes—such as access-point scanning, beacon/probe sniffing, PMKID capture, and client mapping—while maintaining minimal power consumption.
OuroMini serves as an innovative research platform for students, penetration testers, and educators, allowing hands-on exploration of wireless protocol behavior, network security mechanisms, and data-driven signal analytics.

### 1.2 Objective of the Project

The primary objective of OuroMini is to design and develop an embedded wireless security testing and monitoring platform that is cost-efficient, easily deployable, and educationally impactful. The specific goals include:

- To integrate multiple wireless analysis functions—including access-point discovery, signal strength measurement, PMKID sniffing, and packet monitoring—within a single ESP32-based module.
- To eliminate dependence on high-end computing devices by enabling standalone real-time analysis through serial communication.
- To create an extensible and modular firmware structure that can be expanded with additional protocols such as BLE, Sub-GHz, or TinyML-based anomaly detection.
- To support cybersecurity education and training by providing a hands-on, safe, and open-source tool for studying wireless vulnerabilities, authentication behaviors, and data flow patterns.
- To promote affordability and accessibility in wireless research by offering a solution that can be replicated by academic institutions, hobbyists, and professional testers alike.

Ultimately, OuroMini aims to democratize the process of wireless cybersecurity exploration—making advanced scanning, sniffing, and network behavior analysis tools available in a small, energy-efficient, and open-hardware format.

### 1.3 Scope of the Project

The scope of OuroMini encompasses the complete development of a multi-functional, ESP32-based wireless testing system that integrates both hardware and software layers in an optimized embedded framework. It extends across the following dimensions:

- Educational Use: As a hands-on platform for cybersecurity students to learn about Wi-Fi packet structures, AP/STA interactions, and wireless scanning logic without needing a PCdependent setup.
- Research Application: Providing a testbed for lightweight intrusion detection, protocol behavior modeling, and wireless signal pattern visualization.
- Field Operations: Serving as a portable tool for professionals to perform on-site network reconnaissance, audit wireless strength, or detect unauthorized access points.
- Extension and Customization: Its modular architecture allows integration of complementary functions such as BLE sniffing, NFC exploration, or signal triangulation in future firmware updates.

Unlike traditional analyzers, OuroMini has no display dependency, relying instead on serial or web terminal visualization. This design ensures flexibility, minimal power draw, and universal compatibility across operating systems. The simplicity of deployment and open-source firmware makes OuroMini an adaptable foundation for classroom instruction, ethical hacking workshops, or rapid-prototyping scenarios.

## 2. SYSTEM ANALYSIS

## 2.1 Existing System

### 2.1.1 Background & Literature Survey

Before the development of compact, embedded wireless monitoring systems like OuroMini, most network reconnaissance and security analysis tools were limited to computer-based environments requiring dedicated adapters and complex setup procedures. Traditional Wi-Fi auditing systems—such as Aircrack-ng, Wireshark, or Kismet—though powerful, depend on high-performance processors, multiple wireless chipsets in monitor mode, and Linux-based configurations. These requirements make them impractical for lightweight field deployment or real-time embedded experimentation. Moreover, such setups often consume high power, rely on external storage, and lack the immediacy and portability demanded by researchers or students engaging in practical cybersecurity testing.

Over the years, significant advancements have been made in the domain of wireless network security and embedded IoT systems. Researchers have explored methods for passive Wi-Fi scanning, packet sniffing, and device fingerprinting using general-purpose microcontrollers and single-board computers such as the Raspberry Pi, ESP8266, and ESP32. Projects like the ESP8266 Deauther and ESP32 Marauder introduced low-cost methods for packet analysis, network scanning, and basic attack simulation. These systems demonstrated the feasibility of embedding wireless monitoring capabilities into microcontrollers, drastically reducing cost and increasing accessibility. However, many of these early systems suffered from fragmented firmware architectures, lack of modular scalability, and inconsistent performance across network environments.

Academic literature on IoT and cybersecurity education has emphasized the need for portable, affordable, and safe-to-use wireless research platforms that can be integrated into teaching laboratories without regulatory risk. Studies from IEEE and ACM highlight that introducing network reconnaissance concepts through embedded tools fosters deeper understanding of real-world attack surfaces and defense mechanisms. Despite this, most commercially available devices remain either too expensive or too restricted for open experimentation.

In parallel, the growing reliance on Wi-Fi-enabled IoT devices has exposed new vulnerabilities in everyday environments. Research in wireless security testing underscores the necessity of compact field analyzers that can detect rogue access points, analyze channel occupancy, and monitor packet flow anomalies. Yet, existing solutions are primarily software-bound or tethered to full operating systems, creating barriers for mobility and real-time response.

These limitations have collectively inspired the development of OuroMini, a self-contained, firmwaredriven wireless monitoring and security analysis device. Built entirely on the ESP32-WROOM-32, OuroMini consolidates scanning, sniffing, and network interaction functions into a single embedded framework without requiring a PC or external adapter. By leveraging the dual-core capabilities of the ESP32 and its integrated Wi-Fi transceiver, OuroMini overcomes the limitations of traditional software-defined tools—delivering real-time network intelligence through a minimalistic and efficient command interface.

OuroMini thus represents a new generation of embedded cybersecurity systems that merge academic utility, technical sophistication, and operational independence. It bridges the gap between theoretical network security models and hands-on experimentation, providing a scalable foundation for future IoT-oriented intrusion detection, wireless analytics, and embedded AI-driven defense research.

### 2.1.2 Limitations of Existing System

Existing wireless monitoring and network analysis systems exhibit several key limitations that hinder their accessibility, adaptability, and real-time performance in field environments. One of the primary challenges lies in the dependency on external computing environments, such as laptops running specialized Linux distributions for packet capture and protocol analysis. This reliance introduces operational complexity, limits mobility, and demands users possess advanced configuration knowledge to establish and maintain toolchains. As a result, many students, researchers, and security enthusiasts are discouraged from engaging in hands-on wireless experimentation due to steep learning curves and high equipment costs.

Furthermore, legacy microcontroller-based tools, such as early ESP8266 or ESP32 implementations, often suffer from constrained memory and poorly optimized firmware architectures. Many of these systems cannot maintain stable multi-channel scanning or perform concurrent sniffing and analysis operations without system crashes or dropped packets. In addition, their interfaces—frequently limited to serial outputs or basic OLED displays—lack meaningful visualization or structured feedback, making real-time interpretation of captured data difficult.

Another critical limitation of existing solutions is their lack of modularity and unified design. Most available tools operate as single-function utilities, capable of either scanning access points, capturing probe requests, or detecting packets—but rarely integrating these features cohesively. This fragmentation reduces their effectiveness in comparative network testing or educational demonstrations where multiple modes of operation are essential. Likewise, the absence of integrated data logging and cross-protocol interaction (e.g., Wi-Fi, BLE, sub-GHz) restricts the system’s adaptability for broader IoT security studies.

Power efficiency and heat management also remain overlooked aspects in many designs. Conventional devices frequently consume more power than their embedded supplies can sustain, especially during high-frequency channel sweeps or active deauthentication simulations. Combined with the absence of optimized firmware scheduling, this leads to reduced reliability, limited runtime, and eventual hardware instability.

Finally, most previous systems fail to offer a consistent, user-friendly command-line interface (CLI) or structured command management for multi-mode operations. This makes testing and debugging less intuitive, especially for users performing rapid data collection or switching between scanning modes.

These deficiencies collectively emphasize the need for a new generation of embedded wireless research tools that are compact, efficient, modular, and autonomous. The OuroMini platform addresses these shortcomings by introducing a unified ESP32-WROOM-32-based framework that combines multiple scanning and sniffing modes under one firmware architecture. It operates without the need for a host computer, optimizes resource scheduling for stability, and employs a flexible CLI for dynamic control. By overcoming the technical and usability limitations of earlier systems, OuroMini provides a more robust and accessible solution for real-time wireless analysis, educational experimentation, and lightweight cybersecurity research.
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

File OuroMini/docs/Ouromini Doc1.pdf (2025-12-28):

## Application Development Internship

### Project Report on

# OuroMini: Wireless Security Testing Platform

### Submitted by

K. Pardhu | 2311CS040089
K. Karthik | 2311CS040080
K. Tejaswini | 2311CS040077
B. Harshitha | 2311CS040022

### B. Tech III Year I Semester

### Under the Guidance of Dr. G. Latha (Associate Professor)

## Department of CSE (Cyber Security)

## Malla Reddy University, Hyderabad

## November 2025

## CERTIFICATE

### This is to certify that, the Application Development Internship Project entitled “OUROMINI - ESP32-WROOM-32 BASED WIRELESS SECURITY TESTING AND

MONITORING PLATFORM”, has been successfully completed and submitted by K. Pardhu (2311CS040089), K. Karthik (2311CS040080), K. Tejaswini (2311CS040077),

### B. Harshitha (2311CS040022) B.Tech III year I semester, Department of CSE (CS) during November 2025. The results embodied in this report have not been submitted earlier to any other university or institute for any other internship or the award of any

degree or diploma.

Internal Guide | Dean CS, IoT & ECE
Dr. G. Latha | Dr. G. Anand Kumar
(Associate Professor) | (Professor)

External Examiner

## ACKNOWLEDGEMENTS

We extend our sincere gratitude to all those who have contributed to the completion of this project report. Firstly, we would like to extend our gratitude to Dr. V. S. K Reddy, Vice-Chancellor, for his visionary leadership and unwavering commitment to academic excellence.

We would also like to express our deepest gratitude to our project guide Dr. G. Latha Associate Professor, Dept. of Cyber Security & IoT, whose invaluable guidance, insightful feedback, and unwavering support have been instrumental throughout this project for successful outcomes.

We are also grateful to Dr. G. Anand Kumar, Dean, Cyber Security & IoT Dept., for initiating and providing us with the necessary resources and facilities to carry out this project.

We extend our gratitude to our AD –PRC Convener & Coordinator, Dr. G. Latha, for giving valuable inputs and timely guidelines to improve the quality of our project through a critical review process.
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

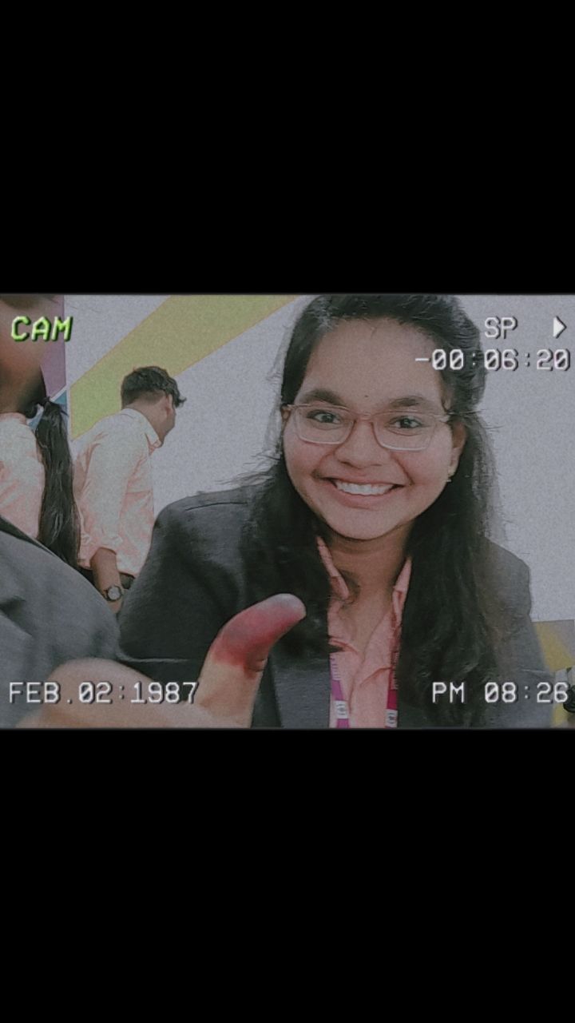
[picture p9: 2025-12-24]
OuroMini/media/Snapchat-800191535.jpg

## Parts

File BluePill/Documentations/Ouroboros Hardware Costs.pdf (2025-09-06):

# Project Ouroboros – Hardware Components & Cost Breakdown

This document provides a detailed list of the hardware components required for Project Ouroboros, covering both defensive (Kickstarter consumer device) and offensive/research (open-source) sides. Prices are estimated in INR and USD, based on common suppliers (AliExpress, Amazon, local Indian electronics markets).

## 1. Core Components

Component | Description | Qty

Price
(INR)

Price
(USD)
ESP32-WROOM/ESP32-S3 Dev Board | Main MCU, Wi-Fi + BLE support,
| low-cost, TinyML capable | 1

₹350–
₹500

$4–6

ESP32 with External Antenna (optional) | For extended range in spectrum
| analysis & jamming tests | 1

₹600–
₹900

$7–10

OLED 1.3” / TFT 2.4” Display | Compact display for real-time
| graphs, menus | 1

₹350–
₹700

$4–8

Touchscreen TFT (2.8–3.2”) | For advanced UI in premium
| defensive version | 1

₹700–
₹1200

$8–14

MicroSD Card Module | For logging packets, replay attack
| profiles | 1

₹80–
₹120

$1–1.5

Li-Po Battery (1200–
2500mAh) | Rechargeable power source | 1

₹350–
₹600

$4–7

TP4056 Charging Module
(with protection) | Li-Po charging & safety | 1

₹50–
₹100

$0.5–1

Boost Converter 5V | Stable power supply | 1

₹60–
₹120

$0.7–1.5

Buttons/Rotary Encoder | For manual control if touchscreen
| not used | 2–3

₹50–
₹150

$1–2

3D Printed / Acrylic
Enclosure | Protective casing, branding-ready | 1

₹500–
₹1000

$6–12

## 2. RF & Wireless Modules

Component | Description | Qty | Price (INR) | Price
| | | | (USD)
nRF24L01+ Module (with PA+LNA) | For RF sniffing, Zigbee-like
| 2.4GHz comms | 1 | ₹150–₹300 | $2–3
CC1101 Sub-GHz Module | 315/433/868/915MHz RF sniffing
| & replay | 1 | ₹300–₹450 | $4–5
HackRF One SDR (optional, advanced) | Full SDR platform (TX/RX, 1–
| 6GHz) | 1 | ₹8,000–
| | | ₹12,000 | $95–140
RTL-SDR USB Dongle (budget option) | RX-only SDR for spectrum
| analysis | 1 | ₹2,000–
| | | ₹3,000 | $25–35
433MHz Antennas (SMA) | For Sub-GHz experiments | 1–2 | ₹200–₹400 | $2–4
2.4GHz Antennas (Wi-Fi/
Bluetooth) | External high-gain antennas | 1–2 | ₹250–₹600 | $3–6

## 3. Defensive Device-Specific (Kickstarter Version)

Component | Description | Qty | Price (INR) | Price
| | | | (USD)
ESP32-S3 Dev Board | More powerful, for TinyML +
| defense monitoring | 1 | ₹600–
| | | ₹900 | $7–10
TFT Display (2.8”–3.2”, Touch) | Full UI with spectrum analyzer | 1 | ₹800–
| | | ₹1200 | $9–14
High-Capacity Li-Po (2500– 4000mAh) | Longer runtime for consumer
| use | 1 | ₹800–
| | | ₹1200 | $9–14

Compact Plastic Case

(Injection Mold Ready) | Kickstarter-ready enclosure | 1 | ₹1000–
| | | ₹1500 | $12–18

Estimated Defensive Device Cost (Kickstarter-ready): - Prototype (DIY build): ~₹2,500–₹4,000 ($30–
48) - Mass Production (1000+ units, molded case): ~₹1,200–₹1,800 ($15–22)

Retail Price Target: ₹3,500–₹5,000 ($40–60)

## 4. Offensive Device-Specific (Open Source)

Component | Description | Qty | Price (INR)

Price
(USD)
CC1101 + nRF24L01+
Combo | Multi-band RF attacks | 1
each | ₹450–₹700 | $6–8
HackRF One / RTL-SDR | For advanced SDR attacks | 1

₹2,000–
₹12,000

$25–140

SD Card (16–32GB) | For packet capture/replay
storage
1 | ₹250–₹400 | $3–5

Estimated Offensive Toolkit Cost (ESP32 + modules, excluding SDR): - ~₹2,000–₹3,000 ($25–35)

With HackRF: ~₹10,000+ ($120+)

## 5. Total Estimated Build Cost

Minimal Defensive Shield (ESP32 + OLED + battery + case): ₹1,200–₹1,800 ($15–22) Advanced Defensive Device (TFT, logging, TinyML, enclosure): ₹2,500–₹4,000 ($30–48) Full Offensive Toolkit (ESP32 + RF modules, no SDR): ₹2,000–₹3,000 ($25–35) Offensive Toolkit + SDR (HackRF/RTL-SDR): ₹10,000–₹15,000 ($120–180)

## 6. Notes on Cost Strategy

Kickstarter Defensive Version → Production cost must be kept below ₹1,800 ($22) per unit to allow for healthy retail margin.
Offensive Open-Source Version → Users build themselves; cost not a concern, since it won’t be sold.
Bundle Strategy → Option to sell Defensive Shield + optional add-on kit (antennas, modules, SDR guides) for hobbyists.

## 7. Conclusion

Project Ouroboros Hardware can be built very cheaply, starting from ₹1,200 ($15) for basic defense, scaling to ₹15,000 ($180) for a full offensive + SDR lab.
The dual-strategy ensures profitability from Kickstarter while ensuring recognition in the hacker/research community via open-source releases.

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
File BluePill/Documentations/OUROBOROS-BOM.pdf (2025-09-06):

Comment | Description | Designator | Footprint | LibRef | Quantity
ANT U.FL | Antenna | ANT1, ANT2, ANT3, ANT4 | U.FL SMD | ANT U.FL | 4
Button | PUSH BUTTON | B1, B2, B3, B4, B5, B6 PUSH BUTTON 4 PIN | SMD 5 | PUSH BUTTON 4 PIN | 6
Button | TACTILE SWITCH | B7 | PUSH BUTTON 12*12*8.5mm | TACTILE SWITCH | 1
BUTTON | PUSH BUTTON | BOOT1, RESET1 | PUSH BUTTON SMD | PUSH BUTTON RIGHT | 2
1042 | | BT1 | BAT_1042 | 1042 | 1
Battery | | BT2 | Bat | Battery | 1
100nf | Capacitor | C1, C3, C5, C6, C7, C8, C13 | CAP0805 | CAP SMD | 7
10uf | Capacitor | C2, C4 | CAP0805 | CAP SMD | 2
Capacitor Tantalum SMD | Capacitor Tantalum SMD | C9, C10 | Tan 1206 (3216X18L) Size A | Capacitor Tantalum SMD | 2
10uf | Capacitor | C11, C12 | CAP 1206 (3216X15L) | CAP SMD | 2
LED | LED | CHG1, Rx1, STD1, Tx1 | L0805 | LED | 4
TP4056 | Complete single cell Li-Ion battery with a constant current / constant voltage linear charger | IC1 | SOP-8 | TP4056 | 1
TYPE-C-31-M-12 | USB Connectors 24 Receptacle 1 8.94*7.3mm RoHS | J1 | HRO_TYPE-C-31-M-12 | TYPE-C-31-M-12 | 1
SMA | SMA Connector Jack, Female Socket 50Ohm Board Edge, End Launch Solder | J2, J3, J4, J5 | SAMTEC_SMA-J-P-H-ST-EM1 | SMA-J-P-H-ST-EM1 | 4
N-Header 10X2 | | P1 | N-Header 10X2 | N-Header 10X2 | 1
S8050 | Bipolar (BJT) Transistor NPN 25 V 500 mA 150MHz 300 mW Surface Mount SOT-23 | Q1, Q2, Q3 | SOT-23 | SMD-TRANSISTORS-NPN-25V-500MW(SOT-23) | 3
4.7k | RESISTOR | R1, R3 | RES 0805 | RES | 2
470 | RESISTOR | R2 | RES 0805 | RES | 1
12k | RESISTOR | R4, R9 | RES 0805 | RES | 2
10K | RESISTOR | R5, R6, R7, R8 | RES 0805 | RES | 4
1k | RESISTOR | R10, R11, R14, R15, R16, R17, R18, R19, R20, R21, R22, R23, R26 | RES 0805 | RES | 13
5.1k | RESISTOR | R12, R13 | RES 0805 | RES | 2
10R | RESISTOR | R24, R25 | RES 0805 | RES | 2
SlideSwitch | SWITCH, SLIDE, SPDT, SMD | SW1 | SWSLIDT_SPDT_MS S3 | SWSLIDT_SPDT_MS S3 | 1
SD CARD SPI MODE | SD CARD SPI MODE | U1 | MICRO SD | SD CARD SPI MODE | 1
ESP32-WROOM-32U | Bluetooth, WiFi 802.11b/g/n, Bluetooth v4.2 +EDR, Class 1, 2 and 3 Transceiver Module 2.4GHz ~ 2.5GHz Antenna Not Included, U.FL Surface Mount | U2 | XCVR_ESP32-WROOM-32U | ESP32-WROOM-32U | 1
CP2102 | USB Bridge, USB to UART USB 2.0 UART Interface 28-QFN _5x5_ | U3 | QFN28G_0.5-5X5MM | INTERFACE-CP2102-GMR(QFN28) | 1
LF33 | 3.3V VOLTAGE REGULATOR | U4 | D-PACK | LF33 | 1
PCF8574T | I/O Expander 8 IÂ²C 100 kHz 20-SSOP | U5 | SOIC127P1032X265-16N | PCF8574T | 1
2.8 240X320_ILI9341 | LCD TFT FULL Color 2.8 240X320 ILI9341 Driver FLAT | U6 | LCDTFT_1.8IN_ST77 35_18P | LCD_TFT_Color_2.8 240X320_ILI9341 Driver_FLAT | 1
XPT2046 | Touch Screen Controller | U7 | TSSOP16 | XPT2046 | 1

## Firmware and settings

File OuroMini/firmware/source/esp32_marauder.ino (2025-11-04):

/* FLASH SETTINGS

Board: LOLIN D32
Flash Frequency: 80MHz
Partition Scheme: Minimal SPIFFS
Upload Speed: 115200
PSRAM: Enabled
*/

/* 
 ESP32 OuroMini Firmware
 Team Ouroboros 2025
 Version 1.0
 Inspired By ESP32 Marauder by JustCallMeRick.
*/

#include "configs.h"

#ifndef HAS_SCREEN
  #define MenuFunctions_h
  #define Display_h
#endif

#include <WiFi.h>
#include "EvilPortal.h"
#include "WebInterface.h"
#include <Wire.h>
#include "esp_wifi.h"
#include "esp_wifi_types.h"
#include <stdio.h>
#include "freertos/FreeRTOS.h"
#include "freertos/task.h"
#include "esp_system.h"
#include "esp_netif.h"
#include "esp_event.h"
#include <Arduino.h>

#ifdef HAS_GPS
  #include "GpsInterface.h"
#endif

#include "Assets.h"
#include "WiFiScan.h"
#ifdef HAS_SD
  #include "SDInterface.h"
#endif
#include "Buffer.h"

#ifdef HAS_FLIPPER_LED
  #include "flipperLED.h"
#elif defined(XIAO_ESP32_S3)
  #include "xiaoLED.h"
#elif defined(MARAUDER_M5STICKC) || defined(MARAUDER_M5STICKCP2)
  #include "stickcLED.h"
#elif defined(HAS_NEOPIXEL_LED)
  #include "LedInterface.h"
#endif

#include "settings.h"
#include "CommandLine.h"
#include "lang_var.h"

#ifdef HAS_BATTERY
  #include "BatteryInterface.h"
#endif

#ifdef HAS_SCREEN
  #include "Display.h"
  #include "MenuFunctions.h"
#endif

#ifdef HAS_BUTTONS
  #include "Switches.h"
  #if (U_BTN >= 0)
    Switches u_btn = Switches(U_BTN, 1000, U_PULL);
  #endif
  #if (D_BTN >= 0)
    Switches d_btn = Switches(D_BTN, 1000, D_PULL);
  #endif
  #if (L_BTN >= 0)
    Switches l_btn = Switches(L_BTN, 1000, L_PULL);
  #endif
  #if (R_BTN >= 0)
    Switches r_btn = Switches(R_BTN, 1000, R_PULL);
  #endif
  #if (C_BTN >= 0)
    Switches c_btn = Switches(C_BTN, 1000, C_PULL);
  #endif
#endif

// ----- Objects -----
WiFiScan wifi_scan_obj;
EvilPortal evil_portal_obj;
Buffer buffer_obj;
Settings settings_obj;
CommandLine cli_obj;

#ifdef HAS_GPS
  GpsInterface gps_obj;
#endif

#ifdef HAS_BATTERY
  BatteryInterface battery_obj;
#endif

#ifdef HAS_SCREEN
  Display display_obj;
  MenuFunctions menu_function_obj;
#endif

#if defined(HAS_SD) && !defined(HAS_C5_SD)
  SDInterface sd_obj;
#endif

#ifdef MARAUDER_M5STICKC
  AXP192 axp192_obj;
#endif

#ifdef HAS_FLIPPER_LED
  flipperLED flipper_led;
#elif defined(XIAO_ESP32_S3)
  xiaoLED xiao_led;
#elif defined(MARAUDER_M5STICKC) || defined(MARAUDER_M5STICKCP2)
  stickcLED stickc_led;
#else
  LedInterface led_obj;
#endif

#ifdef HAS_NEOPIXEL_LED
  Adafruit_NeoPixel strip = Adafruit_NeoPixel(Pixels, PIN, NEO_GRB + NEO_KHZ800);
#endif

uint32_t currentTime = 0;

// ----- Web / Scan LinkedLists -----
#include "Globals.h"   // assumes Globals.h declares/defines accessPoints, probes, webStations etc.

// Timing
unsigned long lastScan = 0;
const unsigned long scanIntervalMs = 5000; // 5s

// --------------------
// Forward declarations
// --------------------
void startAsyncScan();
void onScanDone(void* arg, esp_event_base_t event_base, int32_t event_id, void* event_data);
void backlightOn();
void backlightOff();
void fullWifiRecovery(); // recovery helper

// --------------------
// Idempotent setup guard + debug
// --------------------
static bool setupCompleted = false; // prevents double init within same boot
static esp_event_handler_instance_t scan_done_handler_instance = NULL;

// Helper: readable reset reason
const char* resetReasonToStr(esp_reset_reason_t r) {
  switch(r) {
    case ESP_RST_POWERON: return "POWERON";
    case ESP_RST_EXT: return "EXTERNAL";
    case ESP_RST_SW: return "SOFTWARE";
    case ESP_RST_PANIC: return "PANIC";
    case ESP_RST_INT_WDT: return "INTERNAL WATCHDOG";
    case ESP_RST_TASK_WDT: return "TASK WATCHDOG";
    case ESP_RST_WDT: return "OTHER WATCHDOG";
    case ESP_RST_DEEPSLEEP: return "DEEPSLEEP WAKE";
    case ESP_RST_BROWNOUT: return "BROWNOUT";
    case ESP_RST_SDIO: return "SDIO";
    default: return "UNKNOWN";
  }
}

// Prevent repeated Wi-Fi / scan handler init
static bool wifiInitialized = false;
static bool scanHandlerRegistered = false;

// Background scan control
static bool backgroundScanEnabled = true;   // master switch for background scanning
static bool backgroundScanPaused = false;   // true while sniff/other radio mode is active
static bool pendingBackgroundScan = false;  // set when a scan was requested but couldn't run

// persistent fail counter for recovery
static int scanFailCount = 0;

// --------------------
// Helper globals & functions (must be defined before loop() so they're visible)
// --------------------

// set to true to see background-scan debug messages in Serial
bool showScanLogs = false; // set to true only when debugging

// Check if promiscuous mode is active
bool isPromiscuousEnabled() {
    bool enabled = false;
    // esp_wifi_get_promiscuous returns esp_err_t, but fills a bool via pointer on Arduino/IDF
    // If the SDK differs, you can replace this with whatever function is provided by your SDK.
    esp_err_t rc = esp_wifi_get_promiscuous(&enabled);
    (void)rc; // ignore return code here
    return enabled;
}

// --------------------
// Full Wi-Fi recovery (safe reinit for APSTA mode)
// --------------------
void fullWifiRecovery() {
    Serial.println("💀 Wi-Fi driver recovery triggered...");

    // Stop and deinit to clear driver state
    esp_wifi_stop();
    vTaskDelay(pdMS_TO_TICKS(200));

    // Deinit if possible (ignore errors)
    esp_wifi_deinit();
    vTaskDelay(pdMS_TO_TICKS(100));

    // Reinitialize driver
    wifi_init_config_t cfg = WIFI_INIT_CONFIG_DEFAULT();
    esp_err_t r = esp_wifi_init(&cfg);
    if (r != ESP_OK) {
        Serial.printf("⚠️ esp_wifi_init failed during recovery: %d\n", r);
        return;
    }

    esp_wifi_set_storage(WIFI_STORAGE_RAM);
    esp_wifi_set_mode(WIFI_MODE_APSTA);

    // Re-apply STA config
    wifi_config_t sta_config = {};
    sta_config.sta.scan_method = WIFI_ALL_CHANNEL_SCAN;
    sta_config.sta.sort_method = WIFI_CONNECT_AP_BY_SIGNAL;
    sta_config.sta.threshold.authmode = WIFI_AUTH_OPEN;
    esp_wifi_set_config(WIFI_IF_STA, &sta_config);

    // Re-apply AP config
    wifi_config_t ap_config = {};
    strncpy((char*)ap_config.ap.ssid, "OuroMini", sizeof(ap_config.ap.ssid)-1);
    ap_config.ap.ssid_len = strlen("OuroMini");
    ap_config.ap.channel = 1;
    strncpy((char*)ap_config.ap.password, "ouroboros", sizeof(ap_config.ap.password)-1);
    ap_config.ap.max_connection = 4;
    ap_config.ap.authmode = WIFI_AUTH_WPA_WPA2_PSK;
    esp_wifi_set_config(WIFI_IF_AP, &ap_config);

    // Start driver
    esp_wifi_start();
    vTaskDelay(pdMS_TO_TICKS(250));

    // Re-register scan done handler: unregister first if stale
    if (scan_done_handler_instance != NULL) {
        esp_event_handler_instance_unregister(WIFI_EVENT, WIFI_EVENT_SCAN_DONE, scan_done_handler_instance);
        scan_done_handler_instance = NULL;
    }

    esp_err_t er = esp_event_handler_instance_register(WIFI_EVENT, WIFI_EVENT_SCAN_DONE, &onScanDone, NULL, &scan_done_handler_instance);
    if (er != ESP_OK) {
        Serial.printf("⚠️ Re-registering scan done handler failed: %d\n", er);
    } else {
        if (showScanLogs) Serial.println("✅ Scan done handler re-registered after recovery");
    }

    Serial.println("✅ Wi-Fi stack reinitialized successfully");
}

// --------------------
// Setup
// --------------------
void setup() {
    // Print reset reason early for debugging reboots
    esp_reset_reason_t rr = esp_reset_reason();
    Serial.begin(115200);
    delay(10); // small delay so serial is ready (non-blocking)
    Serial.printf("=== Boot (reset reason=%s) ===\n", resetReasonToStr(rr));

    // Prevent double initialization if setup() is somehow re-entered
    if (setupCompleted) {
        Serial.println("Setup already completed — skipping re-init.");
        return;
    }
    setupCompleted = true; // mark early

    delay(500);

    Serial.println("ESP-IDF version: " + String(esp_get_idf_version()));

    #ifndef HAS_DUAL_BAND
      esp_spiram_init();
    #endif

    #if defined(MARAUDER_M5STICKC) && !defined(MARAUDER_M5STICKCP2)
      axp192_obj.begin();
    #endif

    #ifdef HAS_SCREEN
      pinMode(TFT_BL, OUTPUT);
      backlightOff();
    #endif

    settings_obj.begin();
    buffer_obj = Buffer();

    wifi_scan_obj.RunSetup();
    evil_portal_obj.setup();

    #ifdef HAS_BATTERY
      battery_obj.RunSetup();
    #endif

    #ifdef HAS_SCREEN
      display_obj.RunSetup();
      menu_function_obj.RunSetup();
      display_obj.tft.setTextColor(TFT_WHITE, TFT_BLACK);
      display_obj.tft.drawCentreString("ESP32 OuroMini", TFT_WIDTH/2, TFT_HEIGHT * 0.33, 1);
      display_obj.tft.drawCentreString("Team Ouroboros", TFT_WIDTH/2, TFT_HEIGHT * 0.5, 1);
      display_obj.tft.drawCentreString(display_obj.version_number, TFT_WIDTH/2, TFT_HEIGHT * 0.66, 1);
      backlightOn();
    #endif

    cli_obj.RunSetup();
    Serial.println(F("CLI Ready"));

    // ----------- Proper ESP-IDF network init -------------
    esp_err_t r;

    r = esp_netif_init();
    if (r != ESP_OK) Serial.printf("⚠️ esp_netif_init failed: %d\n", r);

    r = esp_event_loop_create_default();
    if (r != ESP_OK && r != ESP_ERR_INVALID_STATE) // invalid state means already created - ignore
        Serial.printf("⚠️ esp_event_loop_create_default failed: %d\n", r);

    // Create default netifs for STA and AP (needed for esp_wifi_start etc.)
    esp_netif_create_default_wifi_sta();
    esp_netif_create_default_wifi_ap();

    // Initialize Wi-Fi driver
    if (!wifiInitialized) {
        wifi_init_config_t cfg = WIFI_INIT_CONFIG_DEFAULT();
        if (esp_wifi_init(&cfg) != ESP_OK)
            Serial.println("❌ esp_wifi_init failed");
        else
            Serial.println("✅ Wi-Fi driver initialized");

        esp_wifi_set_storage(WIFI_STORAGE_RAM);

        if (esp_wifi_set_mode(WIFI_MODE_APSTA) != ESP_OK) {
          Serial.println("⚠️ esp_wifi_set_mode failed");
        }

        wifi_config_t sta_config = {};
        sta_config.sta.scan_method = WIFI_ALL_CHANNEL_SCAN;
        sta_config.sta.sort_method = WIFI_CONNECT_AP_BY_SIGNAL;
        sta_config.sta.threshold.authmode = WIFI_AUTH_OPEN;
        esp_wifi_set_config(WIFI_IF_STA, &sta_config);

        wifi_config_t ap_config = {};
        strncpy((char*)ap_config.ap.ssid, "OuroMini", sizeof(ap_config.ap.ssid)-1);
        ap_config.ap.ssid_len = strlen("OuroMini");
        ap_config.ap.channel = 1;
        strncpy((char*)ap_config.ap.password, "ouroboros", sizeof(ap_config.ap.password)-1);
        ap_config.ap.max_connection = 4;
        ap_config.ap.authmode = WIFI_AUTH_WPA_WPA2_PSK;
        esp_wifi_set_config(WIFI_IF_AP, &ap_config);

        if (esp_wifi_start() != ESP_OK) {
          Serial.println("❌ esp_wifi_start failed");
        } else {
          Serial.println("✅ SoftAP + STA mode active");
        }

        wifiInitialized = true;
    } else {
      Serial.println("⚙️ Wi-Fi already initialized, skipping duplicate init");
    }

    // small pause to let stack come up
    delay(300);

    // Register scan event (use instance-register to avoid duplicate registrations)
    if (scan_done_handler_instance == NULL) {
      esp_err_t er = esp_event_handler_instance_register(WIFI_EVENT, WIFI_EVENT_SCAN_DONE, &onScanDone, NULL, &scan_done_handler_instance);
      if (er != ESP_OK) {
        Serial.printf("⚠️ esp_event_handler_instance_register failed: %d\n", er);
      } else {
        Serial.println("✅ Scan done handler registered");
      }
    } else {
      Serial.println("Scan done handler already registered (skipping)");
    }

    // --- Initialize Web Interface ---
    webIF.access_points = &accessPoints;
    webIF.WebStations = &webStations;
    webIF.probe_req_ssids = &probes;

    if (!webIF.begin("OuroMini")) Serial.println("❌ WebInterface failed to start!");
    else Serial.println("🌐 WebInterface started on http://192.168.4.1");

    // --- Bind Web Commands to CLI ---
    webIF.onCommand = [&](String cmd) {
        Serial.printf("[WEB CMD] %s\n", cmd.c_str());
        cli_obj.runCommand(cmd.c_str());  // ⬅️ direct CLI handler from CommandLine Engine.
    };

    // --- Kick off first scan ---
    startAsyncScan();
    Serial.println("🚀 Initial scan started...");
}

// --------------------
// Loop
// --------------------
void loop() {
    currentTime = millis();

    if (millis() - lastScan > scanIntervalMs) {
        lastScan = millis();
        startAsyncScan();
    }

    cli_obj.main(currentTime);
    wifi_scan_obj.main(currentTime);
    buffer_obj.save();
    settings_obj.main(currentTime);

    #ifdef HAS_BATTERY
      battery_obj.main(currentTime);
    #endif

    #ifdef HAS_SCREEN
      menu_function_obj.main(currentTime);
      display_obj.main(wifi_scan_obj.currentScanMode);
    #endif

    #ifdef HAS_FLIPPER_LED
      flipper_led.main();
    #elif defined(XIAO_ESP32_S3)
      xiao_led.main();
    #elif defined(MARAUDER_M5STICKC)
      stickc_led.main();
    #else
      led_obj.main(currentTime);
    #endif

    // --- Background scan resume logic ---
    if (backgroundScanPaused && !isPromiscuousEnabled()) {
        backgroundScanPaused = false;
        if (pendingBackgroundScan) {
            pendingBackgroundScan = false;

            // Wait a short adaptive period while driver settles.
            // Poll promiscuous state for up to 2s, then give the driver a
            // little breathing room (650 ms) before trying to start background scan.
            unsigned long t0 = millis();
            while (isPromiscuousEnabled() && (millis() - t0) < 2000) {
                delay(100);
            }

            // Breathe, you silicon piece of fucking driver
            Serial.println("DRIVER COOLDOWN [RX - AP/STA SWITCH]...");
            delay(1200);

            startAsyncScan();
            if (showScanLogs) Serial.println("▶ Background scan resumed");
            else Serial.println("⚠️ Background scan resume attempted (no verbose logs)");
        }
    }

    delay(20);
}

// --------------------
// Backlight helpers
// --------------------
void backlightOn() {
    #ifdef HAS_SCREEN
      #ifdef MARAUDER_MINI
        digitalWrite(TFT_BL, LOW);
      #else
        digitalWrite(TFT_BL, HIGH);
      #endif
    #endif
}

void backlightOff() {
    #ifdef HAS_SCREEN
      #ifdef MARAUDER_MINI
        digitalWrite(TFT_BL, HIGH);
      #else
        digitalWrite(TFT_BL, LOW);
      #endif
    #endif
}

// --------------------
// Async Wi-Fi Scan (silent mode toggle) - improved/resilient version
// --------------------
void startAsyncScan() {
    if (!backgroundScanEnabled) return;       // master switch off
    if (backgroundScanPaused) {
        // we already paused due to sniff mode — mark that we wanted a scan
        pendingBackgroundScan = true;
        return;
    }

    // If radio is in promiscuous mode, pause background scanning and queue request
    if (isPromiscuousEnabled()) {
        backgroundScanPaused = true;
        pendingBackgroundScan = true;
        if (showScanLogs) Serial.println("⏸ Background scan paused (sniff active)");
        return;
    }

    wifi_scan_config_t scanConf = {};
    scanConf.show_hidden = true;
    scanConf.scan_type = WIFI_SCAN_TYPE_ACTIVE;
    scanConf.scan_time.active.min = 100;
    scanConf.scan_time.active.max = 300;

    // Try starting scan with lightweight retries and small recovery steps
    const int maxRetries = 3;
    int attempt = 0;
    esp_err_t err = ESP_FAIL;

    for (attempt = 0; attempt < maxRetries; ++attempt) {
        err = esp_wifi_scan_start(&scanConf, false);
        if (err == ESP_OK) break; // success

        // If state conflict, attempt light recovery (allow driver to settle)
        if (err == ESP_ERR_WIFI_STATE) {
            if (showScanLogs) Serial.printf("⚠️ esp_wifi_scan_start state conflict (attempt %d/%d). Trying light driver recovery...\n", attempt+1, maxRetries);
            // Light recovery: stop/start wifi driver (small pause)
            esp_wifi_stop();
            vTaskDelay(pdMS_TO_TICKS(150));
            esp_wifi_start();
            vTaskDelay(pdMS_TO_TICKS(200));
            // then retry loop
            continue;
        } else {
            // Unexpected error -> log and break (don't keep spinning)
            Serial.printf("⚠️ esp_wifi_scan_start failed: %s\n", esp_err_to_name(err));
            break;
        }
    }

    if (err != ESP_OK) {
        // Still failing after retries -> mark pending so loop() will try again later
        scanFailCount++;
        Serial.printf("🚫 scan start failed (consecutive %d)\n", scanFailCount);

        // trigger full recovery after repeated failures
        if (scanFailCount >= 3) {
            Serial.println("🚨 Persistent scan failures detected — performing full Wi-Fi recovery");
            fullWifiRecovery();
            scanFailCount = 0;
        }

        pendingBackgroundScan = true;
        backgroundScanPaused = true;
        if (showScanLogs) Serial.println("⏸ Background scan paused (ESP_WIFI_STATE_CONFLICT after retries)");
    } else {
        scanFailCount = 0;
        if (showScanLogs) {
            Serial.println("📡 Scan started (async)...");
        }
    }
}

// --------------------
// Scan done callback (silent mode toggle)
// --------------------
void onScanDone(void* arg, esp_event_base_t, int32_t, void* event_data) {
    wifi_event_sta_scan_done_t *info = (wifi_event_sta_scan_done_t*) event_data;

    if (showScanLogs)
        Serial.printf("✅ Scan done: status=%d, number=%d, scan_id=%d\n", info->status, info->number, info->scan_id);

    uint16_t apCount = 0;
    if (esp_wifi_scan_get_ap_num(&apCount) != ESP_OK) {
        if (showScanLogs) Serial.println("⚠️ Failed to get AP count");
        return;
    }

    if (apCount == 0) {
        accessPoints.clear();
        if (showScanLogs) Serial.println("No APs found");
        webIF.updateClients(); // still updates web dashboard
        return;
    }

    wifi_ap_record_t *ap_list = (wifi_ap_record_t*) malloc(sizeof(wifi_ap_record_t) * apCount);
    if (!ap_list) return;

    uint16_t outCount = apCount;
    if (esp_wifi_scan_get_ap_records(&outCount, ap_list) != ESP_OK) {
        free(ap_list);
        return;
    }

    accessPoints.clear();
    for (uint16_t i = 0; i < outCount; ++i) {
        wifi_ap_record_t &r = ap_list[i];
        String ssidStr = (r.ssid && strlen((char*)r.ssid) > 0) ? String((char*)r.ssid) : "";
        char bssidStr[18];
        snprintf(bssidStr, sizeof(bssidStr), "%02X:%02X:%02X:%02X:%02X:%02X",
                 r.bssid[0], r.bssid[1], r.bssid[2], r.bssid[3], r.bssid[4], r.bssid[5]);

        String encType;
        switch (r.authmode) {
            case WIFI_AUTH_OPEN: encType = "Open"; break;
            case WIFI_AUTH_WEP: encType = "WEP"; break;
            case WIFI_AUTH_WPA_PSK: encType = "WPA"; break;
            case WIFI_AUTH_WPA2_PSK: encType = "WPA2"; break;
            case WIFI_AUTH_WPA_WPA2_PSK: encType = "WPA/WPA2"; break;
            case WIFI_AUTH_WPA2_ENTERPRISE: encType = "WPA2-Enterprise"; break;
            case WIFI_AUTH_WPA3_PSK: encType = "WPA3"; break;
            default: encType = "Unknown"; break;
        }

        accessPoints.add(WebAccessPoint(
            ssidStr,
            r.primary,
            false,
            false,
            r.rssi,
            millis(),
            String(bssidStr),
            encType
        ));
    }

    free(ap_list);
    if (showScanLogs)
        Serial.printf("📋 Populated accessPoints with %d entries\n", accessPoints.size());

    // ✅ Always push updates to web dashboard
    webIF.updateClients();
}

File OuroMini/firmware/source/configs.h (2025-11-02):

#pragma once

#ifndef configs_h

  #define configs_h

  #define POLISH_POTATO

  //// BOARD TARGETS
  //#define MARAUDER_M5STICKC
  //#define MARAUDER_M5STICKCP2
  //#define MARAUDER_MINI
  //#define MARAUDER_V4
  //#define MARAUDER_V6
  //#define MARAUDER_V6_1
  //#define MARAUDER_V7
  //#define MARAUDER_V7_1
  //#define MARAUDER_KIT
  //#define GENERIC_ESP32
  //#define MARAUDER_FLIPPER
  //#define MARAUDER_MULTIBOARD_S3
  //#define ESP32_LDDB
  //#define MARAUDER_DEV_BOARD_PRO
  //#define XIAO_ESP32_S3
  //#define MARAUDER_REV_FEATHER
  //#define MARAUDER_CYD_MICRO // 2432S028
  //#define MARAUDER_CYD_2USB // Another 2432S028 but it has tWo UsBs OoOoOoO
  //#define MARAUDER_CYD_GUITION // ESP32-2432S024 GUITION
  //#define MARAUDER_CYD_3_5_INCH
  //#define MARAUDER_C5
  //#define MARAUDER_CARDPUTER
  //#define MARAUDER_V8
  //// END BOARD TARGETS

  #define MARAUDER_VERSION "v1.8.8"

  #define GRAPH_REFRESH   100

  #define DUAL_BAND_CHANNELS 51

  #define MEM_LOWER_LIM 32000   // Minimum free heap (adjust if needed)


  //// HARDWARE NAMES
  #ifdef MARAUDER_M5STICKC
    #define HARDWARE_NAME "M5Stick-C Plus"
  #elif defined(MARAUDER_M5STICKCP2)
    #define HARDWARE_NAME "M5Stick-C Plus2"
  #elif defined(MARAUDER_CARDPUTER)
    #define HARDWARE_NAME "M5 Cardputer"
  #elif defined(MARAUDER_MINI)
    #define HARDWARE_NAME "Marauder Mini"
  #elif defined(MARAUDER_V7)
    #define HARDWARE_NAME "Marauder v7"
  #elif defined(MARAUDER_V7_1)
    #define HARDWARE_NAME "Marauder v7.1"
  #elif defined(MARAUDER_REV_FEATHER)
    #define HARDWARE_NAME "Adafruit Feather ESP32-S2 Reverse TFT"
  #elif defined(MARAUDER_V4)
    #define HARDWARE_NAME "Marauder v4"
  #elif defined(MARAUDER_V6)
    #define HARDWARE_NAME "Marauder v6"
  #elif defined(MARAUDER_V6_1)
    #define HARDWARE_NAME "Marauder v6.1"
  #elif defined(MARAUDER_CYD_MICRO)
    #define HARDWARE_NAME "CYD 2432S028"
  #elif defined(MARAUDER_CYD_2USB)
    #define HARDWARE_NAME "CYD 2432S028 2USB"
  #elif defined(MARAUDER_CYD_3_5_INCH)
    #define HARDWARE_NAME "CYD 3.5inch"
  #elif defined(MARAUDER_CYD_GUITION)
    #define HARDWARE_NAME "CYD 2432S024 GUITION"
  #elif defined(MARAUDER_KIT)
    #define HARDWARE_NAME "Marauder Kit"
  #elif defined(MARAUDER_FLIPPER)
    #define HARDWARE_NAME "Flipper Zero Dev Board"
  #elif defined(MARAUDER_MULTIBOARD_S3)
    #define HARDWARE_NAME "Flipper Zero Multi Board S3"
  #elif defined(ESP32_LDDB)
    #define HARDWARE_NAME "ESP32 LDDB"
  #elif defined(MARAUDER_DEV_BOARD_PRO)
    #define HARDWARE_NAME "Flipper Zero Dev Board Pro"
  #elif defined(XIAO_ESP32_S3)
    #define HARDWARE_NAME "XIAO ESP32 S3"
  #elif defined(MARAUDER_C5)
    #define HARDWARE_NAME "ESP32-C5 DevKit"
  #elif defined(MARAUDER_V8)
    #define HARDWARE_NAME "Marauder v8"
  #else
    #define HARDWARE_NAME "ESP32"
  #endif

  //// END HARDWARE NAMES

 //// BOARD FEATURES
  #if defined(MARAUDER_M5STICKC) || defined(MARAUDER_M5STICKCP2)
    //#define FLIPPER_ZERO_HAT
    #define HAS_MINI_KB
    #define HAS_BATTERY
    #define HAS_BT
    #define HAS_BUTTONS
    //#define HAS_NEOPIXEL_LED
    #define HAS_PWR_MGMT
    #define HAS_SCREEN
    #define HAS_MINI_SCREEN
    #define HAS_SD
    #define USE_SD
    #define HAS_TEMP_SENSOR
    #define HAS_GPS
  #endif

  #if defined(MARAUDER_CARDPUTER)
    //#define FLIPPER_ZERO_HAT
    #define HAS_MINI_KB
    //#define HAS_BATTERY
    #define HAS_BT
    #define HAS_BUTTONS
    //#define HAS_NEOPIXEL_LED
    //#define HAS_PWR_MGMT
    #define HAS_SCREEN
    #define HAS_MINI_SCREEN
    #define HAS_SD
    #define USE_SD
    #define HAS_TEMP_SENSOR
    #define HAS_GPS
  #endif

  #ifdef MARAUDER_MINI
    //#define FLIPPER_ZERO_HAT
    //#define HAS_BATTERY
    #define HAS_MINI_KB
    #define HAS_BT
    #define HAS_BUTTONS
    #define HAS_NEOPIXEL_LED
    //#define HAS_PWR_MGMT
    #define HAS_SCREEN
    #define HAS_MINI_SCREEN
    #define HAS_SD
    #define USE_SD
    #define HAS_TEMP_SENSOR
    #define HAS_GPS
  #endif

  #ifdef MARAUDER_V7
    //#define FLIPPER_ZERO_HAT
    #define HAS_MINI_KB
    #define HAS_BATTERY
    #define HAS_BT
    #define HAS_BT_REMOTE
    #define HAS_BUTTONS
    #define HAS_NEOPIXEL_LED
    //#define HAS_PWR_MGMT
    #define HAS_SCREEN
    #define HAS_FULL_SCREEN
    #define HAS_SD
    #define USE_SD
    #define HAS_TEMP_SENSOR
    #define HAS_GPS
  #endif

  #ifdef MARAUDER_V7_1
    //#define FLIPPER_ZERO_HAT
    #define HAS_MINI_KB
    #define HAS_BATTERY
    #define HAS_BT
    #define HAS_BT_REMOTE
    #define HAS_BUTTONS
    #define HAS_NEOPIXEL_LED
    //#define HAS_PWR_MGMT
    #define HAS_SCREEN
    #define HAS_FULL_SCREEN
    #define HAS_SD
    #define USE_SD
    #define HAS_TEMP_SENSOR
    #define HAS_GPS
    #define HAS_PSRAM
  #endif
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

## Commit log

2025-09-06 Printed Circuit Board
    [pcbouroborosbp.kicad_pcb]
2025-10-18 Major OuroMini Update for Expo. (Thanks To nRFBox by Cifertech)
    [BOM.xlsx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]
2025-10-18 Main Project Folder Renaming
    [pcbouroborosbp-B_Cu.gbr, pcbouroborosbp-B_Mask.gbr, pcbouroborosbp-B_Paste.gbr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]
2025-10-18 Ignore KiCAD-Files folder
    [pcbouroborosbp.kicad_pcb]
2025-10-18 Print by Cifertech
2025-10-21 MAJOR CHANGES
    [BOM.xlsx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]
2025-10-21 We Love Smoochieeee
    [BOM_Bruce_PCB_v2_Smoochiee.xlsx]
2025-10-22 PCB Images
2025-11-02 FIRMWARE DEVELOPMENT UPDATE
    [BOM_Bruce_PCB_v2_Smoochiee.xlsx, Bruce_PCB_Smoochiee_Pick_and_Plack.xlsx]
2026-05-12 infra(Embedded Systems - Ouromini): Cleanup and Updates
    [pyvenv.cfg]
